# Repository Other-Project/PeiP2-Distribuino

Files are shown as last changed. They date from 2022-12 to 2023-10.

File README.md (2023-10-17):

# Distribuino

<p align=center>
  Resultat final<br />
  <span>Projet réalisé par <a href="https://github.com/06Games">Evan Galli</a> et <a href="https://github.com/TeoBaillot">Téo Baillot d'Estivaux</a> dans le cadre du cours d'<b>Électronique avec Arduino</b></span>
</p>

## Documentation

* [Cahier des charges](docs/cahier_des_charges.md)
* [Répartition du travail](docs/repartition_du_travail.md)
* [Rapports de séance et de projet](docs/rapports_de_seance/README.md)

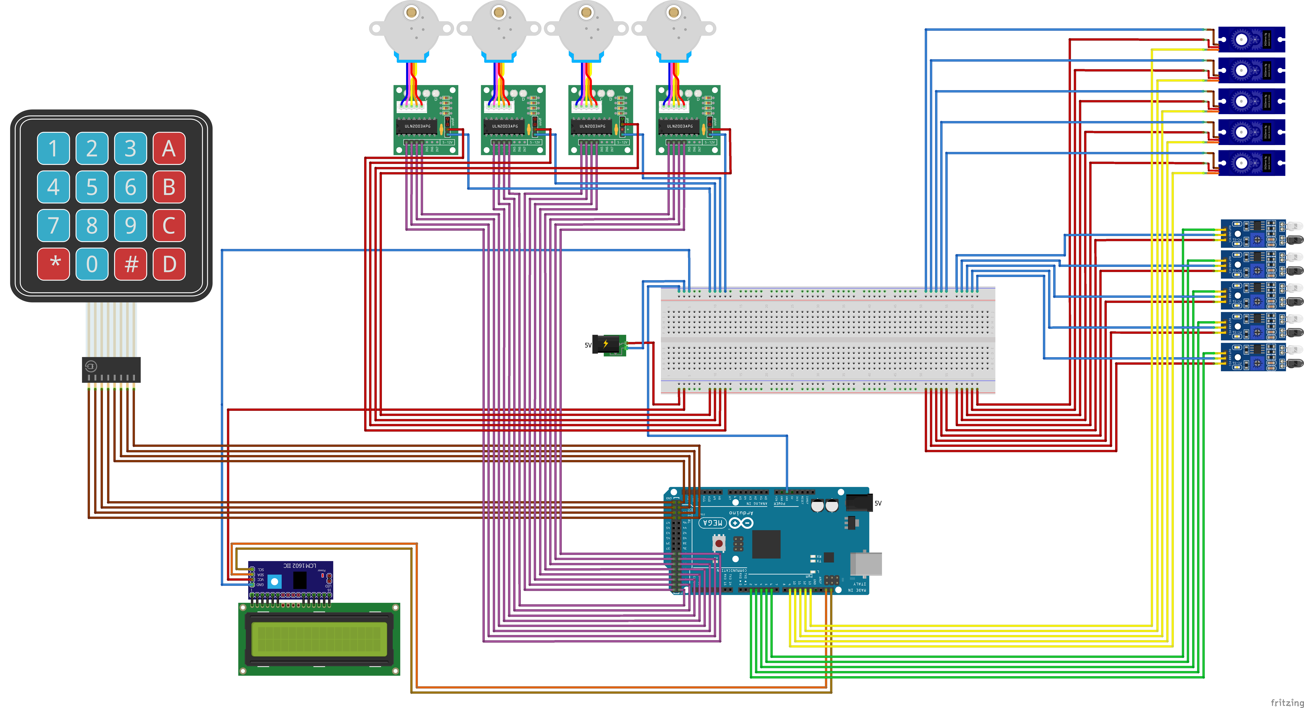
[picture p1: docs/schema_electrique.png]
Schéma électrique


https://github.com/Other-Project/PeiP2-Distribuino/assets/24252743/2bbb648d-e8ed-43b3-9f1b-ac43f1fa2102

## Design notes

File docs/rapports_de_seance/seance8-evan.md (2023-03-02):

# Evan

## Séance 8 : 1 mars 2023

### Fin de la construction des cases

J'ai ajouté le fond sur lequel j'ai fait découper des trous pour les moteurs pas à pas.  
Comme j'avais oublié de faire une encoche pour passer les câbles, j'ai découpé de petites encoches en bas de chaque trous.  
Puis j'ai visser avec des boulons les moteurs pas à pas. 
Malheureusement, il n'y avait pas assez de boulons, je vais devoir en acheter pour visser les moteurs restants.

### Calibrage des capteurs infra-rouge

J'ai essayer de faire fonctionner les capteurs infra-rouge devant capter le passage d'une pièce dans le tube.
Outre certains capteurs defectueux, j'ai remarqué que les capteurs étaient trop éloigné du tube et produisaient beaucoup de faux-positifs.
Téo a donc réduit l'écartement des capteurs à la dremel, ce qui a permi une nette amélioration de la detection.
En revanche, le calibrage n'est toujours pas parfait et la detection ne se fait pas toujours correctement.
Les potentiomètres sont pas assez precis pour un calibrage efficace, comme les capteurs disposent d'une sortie analogique en plus d'une sortie digitale, j'ai la possibilité si necessaire de faire le calibrage dans le code.

https://user-images.githubusercontent.com/24252743/222414979-ab9823aa-37fc-4148-a2f4-29b1150eda77.mp4

### Tests des servo-moteurs servant au rendu des pièces

J'ai fait plusieurs tests pour trouver l'angle nessessaire pour pousser la pièce en dehors du stockage.
En suite, j'ai monté la planche soutenant les pièces sur le reste du distributeur.
Se faisait, j'ai remarqué que la hauteur de certains supports n'etait pas suffisante pour bloquer les pièces supperieure du tube.
Téo a donc fait réimprimer les quelques pièces à changer.

https://user-images.githubusercontent.com/24252743/222415055-9025bd55-9fcc-45de-89fa-96ab0aa629d1.mp4

https://user-images.githubusercontent.com/24252743/222396370-0d3673e9-cfa8-4cbd-a336-67f6afa55b99.mp4

### Réduction du nombre de cables à brancher sur la carte Arduino

Nous avions trop de cables à brancher sur l'arduino mega, j'ai donc du réduire leur nombre.
Pour celà, j'ai utilisé un module HW-061 pour brancher l'écran, ce qui m'as permis de gagner 6 pins sur la carte, ce qui est suffisant ppour tout brancher.

### Correction des problèmes d'alimentation

Au fur et à mesure que je branchait des composants, l'ampérage nessessaire au fonctionnement des éléments était supérieur aux 500mA que peut délivrer la carte Arduino.
Xavier m'as donc dit qu'il fallait procurer 2 alimentations au système, une pour l'arduino (l'inteligence), une pour les composants (la force).

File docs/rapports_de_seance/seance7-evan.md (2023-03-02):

# Evan

## Séance 7 : 15 février 2023

### Construction de la "carcasse"

La dernière fois, nous avions fait découper les planches necessaires à la construction de la boîte.
Lors de la séance, j'ai effectué les forrages obliques afin de pouvoir les visser entre-elles sans que le bois n'éclate et sans que les fixations soit visible de l'exterieur.
En suite, Téo m'a aider à tenir les planches pendant que je les vissais.



### Construction des cases hébergeant les objets

J'ai proposé à Téo de créer des encoches dans les planches constituant les cases afin de pouvoir construire les cases d'un seul tenant, sans nessessité d'ajouter des équaires pour chaque planche.  
Téo a réalisé le dessin vectoriel necessaire et j'ai lancé la découpe sur du bois de 5mm d'épaisseur.  
J'ai en suite pu les assembler. L'assemblage s'est déroulé comme prévu et en très peu de temps (temps, qui est précieux en cette fin de projet), les planches sont bien fixées entre-elles et ne bougent pas.  


### Collage de la glissière du monnaiyeur

J'ai collé la glissière au dessus de la rampe. Celle-ci évite que la pièce ne puisse sortir du rail ainsi que d'éviter qu'elle ne se mette à rouler ce qui empecherait le tri.



### Découpage de la planche de séparation entre les cases et le monnaiyeur

J'ai tracé les traits de découpe sur une planche de 10mm d'épaisseur, puis j'ai demandé à la faire découper.  
Cette planche de 45 cm (L) x 40 cm (H) soutiendra le monnaiyeur puisque les divers élements de celui-ci seront fixés dessus.

### Collage des éléments du monnaiyeur à la planche de séparation

J'ai déterminé les inclinaisons necessaires à ce que les pièces glissent bien (et soient bien triées) tout en minimisant la hauteur occupée.  
J'ai alors déterminé que l'angle du rail devrait etre de 17° et celui de la rampe de rendu de 11°.
Nous avons en suite procédé à leur collage sur la planche de séparation précédamment découpée.


### Détermination de la position des servo-moteurs sur la planche de stockage des pièces

Nous avons (à la louche) déterminé la position des servo-moteurs sur la planche de stockage.
En suite, Téo a fait découper au laser la planche de soutient des pièces et a vissé les servo-moteurs.

https://user-images.githubusercontent.com/24252743/219320475-cbd0ec37-855c-4c8b-9518-73eb0a488ce1.mp4

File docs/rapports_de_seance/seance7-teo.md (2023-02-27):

# Séance 7 Téo Baillot d'Estivaux:  

Depuis la dernière séance on a surtout travaillé à l'assemblage de notre distributeur automatique. J'ai donc fait quelques découpes laser et quelques modélisations 3d dont on avait besoin.  

## Les découpes laser : 

J'ai fait une première découpe laser pour faire une planche qu'on a mis en dessous des tubes afin de soutenir les pièces, la planche comporte des trous qui permettent de fixer les servo-moteurs qui feront tomber les pièces pour rendre la monnaie et d'autres trous qui laisseront simplement passer les pièces de 1, 2, et 5 centimes que nous n'accepteront pas car elles seraient trop compliquées à gérer dans le rendu de la monnaie à cause de leur épaisseur trop faible. Les mesures des endroits qui devaient accueillir les servo-moteurs étaient assez compliquées à faire mais nécessitaient une grande précision donc j'ai dû refaire la planche une seconde fois après un premier essai qui n'avait pas marché. 

  

J'ai également fait les découpes laser des cases qui accueilleront les produits que l'on fera tomber, Evan a eu l'idée de les faire de telle façon qu'elles s'emboitent ce qui nous permet de les monter très rapidement et d'avoir une fixation assez solide.  

  

  

  

J'ai aussi fait la planche qui viendra derrière les cases pour supporter les moteurs pas à pas qui permettront de faire tomber les objets du distributeur.  

  

  

## Les modélisation 3d :  

J'ai fait des supports que l'on va coller sur la planche qui supporte les servo-moteurs car il doit y avoir un écart très précis entre le bas du tube et là où les pièces seront retenues. Cependant, j'ai oublié de tenir compte de la hauteur qui dépasserait du servo-moteur donc j'ai dû recommencer.
Les supports sont de simple carré avec différentes hauteurs qui nous permettent d'adapter la distance entre le bas d'un tube et là où on retient les pièces.  

  

J'ai aussi modélisé des pièces que l'on fixera sur le haut des servo-moteurs car celles qu'on nous donnait n'étaient pas assez longues et ne correspondaient donc pas à nos besoins. J'ai fait le test en imprimant une de ces pièces et elle fonctionne donc j'ai lancé l'impression des autres.  
J'ai fait 3 versions:  

La version 1 :  

Cette première version est assez simple, mais je lui ai trouvé quelques problèmes comme le manque d'un trou pour visser sur le servo-moteur.  

  

  

La version 2 :  

Cette seconde version est plus travaillée, plus fidèle à ce qu'on nous avait donné, mais après réflexion, elle poserait des problèmes à l'impression 3d par exemple à cause des supports que l'on ne pourrait pas enlever à cause de la très faible épaisseur (1.8mm) du bâton qui sort du cylindre.  

  

  

La version 3 :  

J'ai finalement choisi de garder cette version car je me suis dit que c'est celle qui poserait le moins de problème lors de l'impression 3d, je l'ai donc faite avec différentes hauteurs pour que ça s'adapte aux différents supports qui soutiendront les pièces.



  

  

## La partie construction :  

On a assemblé tous les côtés de la boîte à deux car les planches étaient assez lourdes et qu'on voulait être sûr de les mettre correctement, on a décidé de ne pas fixer la partie haute pour le moment ce qui nous permet de manipuler tout ce qu'on met à l'intérieur de la boîte plus facilement et de garder la face avant pour plus tard car on ne connaît pas encore la postion exacte de l'encoche qu'on devra faire pour insérer les pièces. On a fait les découpes et mesures des planches ensemble mais c'est evan qui a fait les trous qui permettront de visser les planches.

  

  

J'ai vissé les capteurs infrarouges dans du bois que j'ai ensuite collé sur les tubes à l'endroit prévu. On a décidé de d'abord visser les capteurs dans du bois pour éviter de visser dans le plastique de peur que ça casse.  

  

J'ai ensuite vissé tous les servo-moteurs sur la planche qui leur était destinée (une première fois à l'envers donc j'ai du tout démonté pour tout refaire car je n'avais pas fait attention).  

  

On a collé les différentes parties du rail qui trie les pièces ensemble :  

  

  

On a ensuite décidé de commencer à construire la partie trieur de pièces, on a donc collé la rampe qui trie les pièces en fonction de leur taille ainsi que toute la partie avec les tubes ( on a préféré le faire à deux car il fallait être assez précis).  

    

  

  

  

## Le test:  

On a testé le fonctionnement des servo-moteurs qui permettront de rendre la monnaie :  

https://user-images.githubusercontent.com/79744829/219315831-a52dc6ba-7ef4-4b65-8d2b-ec19ad241fc2.mp4  

## Conclusion :  

On rattrape petit à petit le retard que l'on a pris à cause du trieur de pièce et le projet commence à prendre forme, on va continuer de travailler en dehors des cours sur le projet sinon on ne pourra pas le finir mais si le rendu de la monnaie fonctionne correctement ( c'est ce qui nous fait le plus peur) on devrait pouvoir rendre notre projet fonctionnel dans les temps.

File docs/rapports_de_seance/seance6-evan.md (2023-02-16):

# Evan

## Séance 6 : 8 février 2023

### Retrait des supports des tubes qui contiendront les pièces

Téo avait fait imprimer les tubes qui contiendront les pièces, ces tubes avaient des supports un peu partout, 
je l'ai donc aidé à enlever les supports d'une partie des tubes pendant qu'il s'occupait des autres

### Collage des divers éléments du monnayeur

#### Trieur

Nous avons collé une petite planche le long de la planche de tri, cette planche soutiendra les pièces lors de leur descente le long du rail de tri.  
Cette planche permet de soutenir les pièces lors de leur descente.  
À la prochaine séance, nous ajouterons une planche de guidage par-dessus pour nous assurer que la pièce reste bien à plat et ne se mette pas à rouler.  
Cela nous permet aussi de nous assurer que la pièce ne sortira pas du rail si l'utilisateur la lance avec une impulsion vers le haut.  
Nous avons déterminé que nous devions pencher le rail de 40° afin que le tri se fasse bien et que nous devions appliquer une pente de 20° afin que la pièce glisse bien.  
Ainsi, afin de pouvoir ultérieurement fixer le rail à une surface verticale, nous avons fait découper de petits tasseaux.






#### Réception

Avec Téo, nous avons collé les différents tubes et glissières sur la planche de réception en bois qu'il avait fait découper au laser.  
Malheureusement, lors du collage, nous n'avons pas réussi à bien positionner les glissières, ce qui cause un décalage au fur et à mesure.  
Nous espérons que cela ne causera pas trop de problèmes.  
La planche de réception étant inclinée de 20° (afin que les pièces glissent bien), nous avons dû faire découper des tasseaux afin de pouvoir la fixer à une surface verticale.







https://user-images.githubusercontent.com/24252743/217789593-29e0c0b9-aa57-4225-9f6d-d5b33a9a447c.mp4

### Détermination des dimensions de notre distributeur

Grâce aux différentes inclinaisons obtenues lors de nos tests, nous avons pu déterminer les dimensions totales du distributeur.  
Notre distributeur mesurera donc 50 cm (l) x 50 cm (L) x 44 cm (H)  
Nous avons ensuite fait découper les différentes faces.

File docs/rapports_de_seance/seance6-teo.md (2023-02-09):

# Séance 6 Téo Baillot d'Estivaux:  

Aujourd'hui on a commencé l'assemblage de notre distributeur car j'ai fait chez moi les modélisations et découpes laser nécessaires à l'assemblage du trieur de pièce et on a fait des tests sur le trieur de pièces.  

## Les modélisations :  

J'ai refait la modélisation des tubes et des rampes qui étaient trop compliquées à faire en bois.  

  

  

## Les découpes laser :  

J'ai fait les découpes laser du guide qui sera juste au-dessus de celle qui trie les pièces en fonction de leur taille afin d'éviter que la pièce saute et être sûr que le tri se fait correctement.  

  

La rampe qui va guider les pièces vers le tube :  

  

La rampe qui ramènera la monnaie rendu à l'utilisateur :  

  

## Le début de l'assemblage :  

On a découpé les planches pour faire l'extérieur de la boite et une planche qui viendra à l'intérieur de la boîte sur laquelle on va fixer le système de trie des pièces, on a enlevé tous les supports des modélisations 3d, on a collé tous les tubes et tous les guides sur la rampe qui accompagne les pièces aux tubes, et on a fait des tasseaux pour soutenir la rail qui triera les pièces en fonction de leur taille et le rail qui guide les pièces vers les tubes.  

  

  

  

  

  

  

  

## Les tests :  

On a testé les différentes positions d'angles dans laquelle on pourrait mettre la rampe qui trie les pièces en fonction de leur taille ce qui nous a permis de déterminer la taille que prendra le système de trie et dimensionner la boîte.  

On a aussi testé que les pièces étaient bien guidées dans la rampe qui va vers les tubes et qu'elles rentraient correctement dans les tubes :  

https://user-images.githubusercontent.com/79744829/217796409-5acfa904-5b46-4af0-a7f6-d8ce901cf2a7.mp4  

## Conclusion :  

Notre projet commence à prendre forme et on s'est rendu compte que la construction va nous prendre beaucoup plus de temps que prévu. Il y a beaucoup de choses dans le compte-rendu car j'ai travaillé entre les séances.

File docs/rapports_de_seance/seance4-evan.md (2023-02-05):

# Evan

## Séance 4 : 18 janvier 2023

### Présentation orale du projet

Avec Téo, nous avons présenté notre projet durant 5 minutes à un jury composé de M. Charlon et de M. Peter puis, tous deux nous on posé quelques questions et on émit des recommandations pour la suite du projet.

### Gestion des articles

J'ai implémenté un système de gestion des articles capable de connaitre le prix des articles ainsi que de vérifier la validé du code entré

Dans un premier temps, j'ai utilisé la librairie [Dictionary](https://www.arduino.cc/reference/en/libraries/dictionary/) qui m'a permis d'associer un prix à un code article

```cpp
#include <Keypad.h>
#include <LiquidCrystal.h>
#include <Stepper.h>

const int ROW_NUM = 4; //four rows
const int COLUMN_NUM = 4; //four columns
char keys[ROW_NUM][COLUMN_NUM] = {
  {'1','2','3', 'A'},
  {'4','5','6', 'B'},
  {'7','8','9', 'C'},
  {'*','0','#', 'D'}
};
byte pin_rows[ROW_NUM] = {47, 49, 51, 53}; //connect to the row pinouts of the keypad
byte pin_column[COLUMN_NUM] = {46, 48, 50, 52}; //connect to the column pinouts of the keypad
Keypad keypad = Keypad(makeKeymap(keys), pin_rows, pin_column, ROW_NUM, COLUMN_NUM);

LiquidCrystal lcd(31, 33, 35, 30, 32, 34);

const int stepsPerRevolution = 2048;
const int rpm = 16;
Stepper stepper1 = Stepper(stepsPerRevolution, 8, 10, 9, 11);

Dictionary &d = *(new Dictionary(4));

const int codeLength = 4;
String productCode = "";

void setup(){
  Serial.begin(9600);
  lcd.begin(16, 2);
  stepper1.setSpeed(rpm);
  d("123A", 2.5);
  d("456B", 2.0);
}

void loop(){
  char key = keypad.getKey();

  if (key) {
    if(key == '*' | key == '#') productCode = ""; // Cancel
    else if(productCode.length() < codeLength) productCode += key;
  }
  
  writeToScreen(0, "Distribuino v0.3");
  if(productCode == "") writeToScreen(1, "Code produit ?");
  else if(productCode.length() == codeLength) 
  {
    if(d(productCode)) {
        writeToScreen(1, "Inserer " + String(d[productCode]) + "e");
        delay(5000);
        writeToScreen(1, "Distribution...");
        stepper1.step(-stepsPerRevolution);
        productCode = "";
    }
  }
  else writeToScreen(1, productCode);
}

void writeToScreen(int line, String text) {
  // Clears the screen line
  for(int i = 0; i < 16; i++){
    lcd.setCursor(i, line);
    lcd.write(" ");
  }

  // Writes the text
  lcd.setCursor(0, line);
  lcd.print(text);
}
```

https://user-images.githubusercontent.com/24252743/213459873-f7ff2302-5194-409e-a2dc-9b17383bf209.mp4

En suite, j'ai souhaité pouvoir afficher le nom de l'article sélectionné, j'ai donc créé une structure afin de faciliter l'accès aux données
```cpp
struct Item {
  String itemCode;
  String itemName;
  float itemPrice;
};
```

Mais je me suis rendu compte que la librairie que j'utilisais pour le dictionnaire ne les supportait pas.  
J'ai donc opté pour utiliser une simple liste dans laquelle le programme va itérer à la recherche de l'article

```cpp
#include <Keypad.h>
#include <LiquidCrystal.h>
#include <Stepper.h>
#include <Dictionary.h>

struct Item {
  String itemCode;
  String itemName;
  float itemPrice;
};

const int ROW_NUM = 4; //four rows
const int COLUMN_NUM = 4; //four columns
char keys[ROW_NUM][COLUMN_NUM] = {
  {'1','2','3', 'A'},
  {'4','5','6', 'B'},
  {'7','8','9', 'C'},
  {'*','0','#', 'D'}
};
byte pin_rows[ROW_NUM] = {47, 49, 51, 53}; //connect to the row pinouts of the keypad
byte pin_column[COLUMN_NUM] = {46, 48, 50, 52}; //connect to the column pinouts of the keypad
Keypad keypad = Keypad(makeKeymap(keys), pin_rows, pin_column, ROW_NUM, COLUMN_NUM);

LiquidCrystal lcd(31, 33, 35, 30, 32, 34);

const int stepsPerRevolution = 2048;
const int rpm = 16;
Stepper stepper1 = Stepper(stepsPerRevolution, 8, 10, 9, 11);

Item items[] = {
  {"123A", "Bonbons", 2.5},
  {"456B", "Kitkat", 2.0},
  {"789C", "", 2.1},
  {"0000", "C'est un code pin", 3.0}
};

const int codeLength = 4;
String productCode = "";

void setup(){
  Serial.begin(9600);
  lcd.begin(16, 2);
  stepper1.setSpeed(rpm);
}

void loop(){
  char key = keypad.getKey();

  if (key) {
    if(key == '*' | key == '#') productCode = ""; // Cancel
    else if(productCode.length() < codeLength) productCode += key;
  }
  
  writeToScreen(0, "Distribuino v0.3");
  if(productCode == "") writeToScreen(1, "Code produit ?");
  else if(productCode.length() == codeLength) 
  {
    for(int i = 0; i <= 4; i++){
      if(i == 4)
      {
        writeToScreen(1, "Code invalide");
        delay(5000);
        productCode = "";
      }
      else if(items[i].itemCode == productCode) {
        writeToScreen(0, items[i].itemName);
        writeToScreen(1, "Inserer " + String(items[i].itemPrice) + "e");
        delay(5000);
        writeToScreen(1, "Distribution...");
        stepper1.step(-stepsPerRevolution);
        productCode = "";
        break;
      } 
    }
  }
  else writeToScreen(1, productCode);
}

void writeToScreen(int line, String text) {
  // Clears the screen line
  for(int i = 0; i < 16; i++){
    lcd.setCursor(i, line);
    lcd.write(" ");
  }

  // Writes the text
  lcd.setCursor(0, line);
  lcd.print(text);
}
```

https://user-images.githubusercontent.com/24252743/213457605-0a6aa33a-0515-48f7-81d4-5080b71538fd.mp4

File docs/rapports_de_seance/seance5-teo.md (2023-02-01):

# Séance 5 Téo Baillot d'Estivaux:  
Aujourd'hui on a récupéré la modélisation 3d du trieur de pièce qui a été imprimé mais on a fait face à de nombreux problèmes. La pièce avait été découpée en deux morceaux et ni l'un ni l'autre n'a été utilisable. Je me suis donc résolu à refaire le système de tri depuis le début en grande partie en bois plutôt que de le réimprimer.  

## Les problèmes de la partie haute de la modélisation:  

Je me suis rendu compte que j'avais fait une erreur de cotation lors de la modélisation, les dimensions de la fente pour insérer les pièces étaient trop petites et l'écart entre le rail pour trier les pièces et le rail d'au-dessus qui devait permettre de guider les pièces qui avaient le même espacement que la fente était donc trop petite aussi. On a donc voulu limer la fente pour l'agrandir et retirer le rail qu'il y avait au-dessus du rail pour retenir les pièces avec une dremel mais cela a fait fondre le plastique et nous a donc rajouté un problème. On a donc ensuite essayé de poncer le plastique pour le remettre à la hauteur voulue mais c'était très imprécis et a changé l'écart entre l'endroit où devait rouler la pièce et le haut de chaque trou du rail pour trier les pièces.
On a donc réussi à faire en sorte que les pièces soient triées mais elles ne se triaient pas comme on le voulait et comme ce n'était parfaitement lisse parfois les pièces sautaient.  

De plus, on avait récupéré la partie haute avec quelques endroits du bas cassés au niveau du guide vers le tri de stockage.  

  

  

https://user-images.githubusercontent.com/79744829/216055010-b539d415-488c-426f-9a1e-61f5f9b7d00a.mp4  

Face à tous ses problèmes et malgré plus d'une heure de tentatives pour régler le problème on a décidé d'abandonner la partie haute du système de tri à notre plus grand regret.

## Les problèmes de la partie basse de la modélisation:  

La partie basse a eu beaucoup de problèmes mais qui cette fois-ci n'étaient pas liés à moi mais à des problèmes de modélisation.

Tout d'abord, il y a eu énormément des supports qui ont surement fondu lors de l'impression et qui sont devenu aussi solides que la partie que l'on voulait garder donc c'était très difficile de les enlever.

De plus, la modélisation a été imprimée à plat alors que notre pièce avait un angle donc il y a eu une grosse couche imprimée dont on ne voulait pas:  

  

  

  

Il y avait aussi des supports impossibles à enlever qui bouchaient les tubes de stockage des pièces et des supports qui étaient aussi très difficiles à enlever au-dessus et en dessous des plateformes qui devaient accueillir les servo-moteurs et retenir les pièces ne faisant qu'un bloc de plastique donc impossible d'enlever de façon suffisamment précise pour que la plateforme reste à 1.5 fois l'épaisseur d'une pièce en dessous du tube:  

  

On a tout de même essayé d'enlever les supports mais au bout d'une heure on a bien vu qu'on n'arriverait pas à tout enlever comme on voulait donc on a aussi, a notre plus grand regret, abandonné la partie basse de la modélisation.

## La solution:  

J'ai passé énormément de temps à faire la modélisation et on a passé beaucoup de temps à essayer de résoudre les problèmes une fois qu'elle avait été imprimée donc on a perdu énormément de temps pour faire le trieur en modélisation 3d sans succès.  

Je tiens quand même à ce qu'on ait un trieur de pièce donc je ne vais pas abandonner et je vais en refaire un mais cette fois il sera principalement en bois. 

## Le début du nouveau trieur:  

J'ai découvert le site Inkscape pour faire des découpes laser que j'ai donc dû prendre en main et j'ai fait la rampe de trie des pièces qui cette fois marche. 



https://user-images.githubusercontent.com/79744829/216062290-51b9a979-9d02-46e9-9bfa-1d73d8cbd94c.mp4  

J'ai aussi refait des modélisations de tubes qui ressemblent au premier en modélisation 3d car j'ai pensé que pour les tubes la modélisation 3d restait le plus simple. J'en ai fait un et l'ai fait imprimer pour voir si ça marchait avant de faire et d'imprimer les autres sauf qu'il y a encore eu un problème à l'impression car les supports qui ont été mis était aussi durs que la modélisation donc ne pouvait pas être enlevés et remplissaient l'intérieur de tube empêchant les pièces de passer. On a donc relancer une nouvelle fois l'impression.  

  

## Conclusion:  

Dans ce compte rendu je raconte beaucoup de choses car j'ai passé beaucoup de temps à travailler le projet en dehors des cours pour rattraper le retard accumulé.  

Je repars donc de 0 pour faire le système de tri des pièces mais reste très motivé.

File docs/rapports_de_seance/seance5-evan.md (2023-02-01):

# Evan

## Séance 5 : 1 février 2023

### Travail au FabLab

> Voir le [compte rendu de Téo](seance5-teo.md) pour plus de détails sur les problèmes rencontrés

J'ai aidé Téo à enlever les supports de la partie basse de notre système de tri qui a été imprimé durant la semaine de ski.  
Malgrès tout nos efforts, la pièce reste innutilisable, les supports étant plus dure que la pièce elle-même.

En suite, nous avons essayé de corriger une erreure de cotation sur la rampe de tri, nous avons retiré la partie suppérieure de la rampe à la Dremel car celle-ci était trop proche de la rampe en elle-même. En retirant la partie suppérieure, le soutient des pièces avait en partie fondu, ce qui couplé avec une marge de seulement 1mm en bas des trous, ne permettait plus le passage des pièces. Nous avons alors poncé le support, mais en poncant, nous avons retirer plus de matière que necessaire et les pièces ne tombait plus dans les bons compartiments.

Nous nous somme résolus à refaire entièrement le système de tri, mais en limitant cette fois l'impression 3D au strict minimum, le reste sera fait en bois.

### Amélioration de la lisibilité du code

J'ai divisé le code en plusieurs fonctions afin d'en améliorer la lisibilité ainsi que pour en faciliter la modification dans le futur.
Afin de passer l'article séléctionné d'une fonction à une autre, j'ai utilisé un pointeur ce qui à l'avantage de pouvoir renvoyer une valeur `null` contrairement à un passage d'instance classique et qui permet un accès direct à l'article contrairement à l'index.

```cpp
#include <Keypad.h>
#include <LiquidCrystal.h>
#include <Stepper.h>

struct Item {
  String itemCode;
  String itemName;
  float itemPrice;
};

const int ROW_NUM = 4; //four rows
const int COLUMN_NUM = 4; //four columns
char keys[ROW_NUM][COLUMN_NUM] = {
  {'1','2','3', 'A'},
  {'4','5','6', 'B'},
  {'7','8','9', 'C'},
  {'*','0','#', 'D'}
};
byte pin_rows[ROW_NUM] = {47, 49, 51, 53}; //connect to the row pinouts of the keypad
byte pin_column[COLUMN_NUM] = {46, 48, 50, 52}; //connect to the column pinouts of the keypad
Keypad keypad = Keypad(makeKeymap(keys), pin_rows, pin_column, ROW_NUM, COLUMN_NUM);

LiquidCrystal lcd(31, 33, 35, 30, 32, 34);

const int stepsPerRevolution = 2048;
const int rpm = 16;
Stepper stepper1 = Stepper(stepsPerRevolution, 8, 10, 9, 11);

Item items[] = {
  {"123A", "Bonbons", 2.5},
  {"456B", "Kitkat", 2.0},
  {"789C", "", 2.1},
  {"0000", "C'est un code pin", 3.0}
};

const int codeLength = 4;

void setup() {
  Serial.begin(9600);
  lcd.begin(16, 2);
  stepper1.setSpeed(rpm);

  for(int i = 0; i < captors; i++) pinMode(coinCaptors[i].pin, INPUT);
}

void writeToScreen(int line, String text) {
  // Clears the screen line
  for(int i = 0; i < 16; i++){
    lcd.setCursor(i, line);
    lcd.write(" ");
  }

  // Writes the text
  lcd.setCursor(0, line);
  lcd.print(text);
}

String waitForCode(){
  writeToScreen(0, "Distribuino v0.3");
  writeToScreen(1, "Code produit ?");

  String productCode = "";
  while(productCode.length() < codeLength) {
    char key = keypad.getKey();
    if (key) {
      if(key == '*' | key == '#') return waitForCode(); // Cancel
      else productCode += key;
      
      writeToScreen(1, productCode);
    }
  }
  return productCode;
}

Item* checkCode(String productCode) {
  for(int i = 0; i <= 4; i++) {
      if(i == 4)
      {
        writeToScreen(1, "Code invalide");
        delay(5000);
        productCode = "";
        return NULL;
      }
      else if(items[i].itemCode == productCode) {
        writeToScreen(0, items[i].itemName);
        writeToScreen(1, "Inserer " + String(items[i].itemPrice) + "e");
        return &items[i];
      }
    }
}

void waitForCoins(Item* item) {
  delay(5000);
}

void loop() {
  String productCode = waitForCode();
  Item* item = checkCode(productCode);
  if (item == NULL) return;

  waitForCoins(item);
  writeToScreen(1, "Distribution...");
  stepper1.step(-stepsPerRevolution);
}
```

### Détection des pièces

Après avoir nétoyé le code, je me suis attelé à la détection des pièces.
Il y aura un capteur pour chaque pièces (la valeur ayant été trié grace à une rampe qui fait tomber les pièces en fonction de leur taille).
Il me suffit donc de compter le nombre de passage devant chaque capteur pour déterminer la valeur des pièces incérées.
La fonction `waitForCoins` que j'ai prévu à cet effet, retourne un `float` qui contient la valeur à rendre à la fin de la transaction (dans le cas, où l'utilisateur a mis plus que nécessaire).

```cpp
#include <Keypad.h>
#include <LiquidCrystal.h>
#include <Stepper.h>

struct Item {
  String itemCode;
  String itemName;
  float itemPrice;
};

struct Coin {
  int pin;
  float coinValue;
};

const int ROW_NUM = 4; //four rows
const int COLUMN_NUM = 4; //four columns
char keys[ROW_NUM][COLUMN_NUM] = {
  {'1','2','3', 'A'},
  {'4','5','6', 'B'},
  {'7','8','9', 'C'},
  {'*','0','#', 'D'}
};
byte pin_rows[ROW_NUM] = {47, 49, 51, 53}; //connect to the row pinouts of the keypad
byte pin_column[COLUMN_NUM] = {46, 48, 50, 52}; //connect to the column pinouts of the keypad
Keypad keypad = Keypad(makeKeymap(keys), pin_rows, pin_column, ROW_NUM, COLUMN_NUM);

LiquidCrystal lcd(31, 33, 35, 30, 32, 34);

const int stepsPerRevolution = 2048;
const int rpm = 16;
Stepper stepper1 = Stepper(stepsPerRevolution, 8, 10, 9, 11);

const int captors = 1;//5;
const Coin coinCaptors[] = {
  {41, 0.5},
  /*{42, 0.2},
  {43, 0.5},
  {44, 1.0},
  {45, 2.0}*/
};

Item items[] = {
  {"123A", "Bonbons", 2.5},
  {"456B", "Kitkat", 2.0},
  {"789C", "", 2.1},
  {"0000", "C'est un code pin", 3.0}
};

const int codeLength = 4;

void setup() {
  Serial.begin(9600);
  lcd.begin(16, 2);
  stepper1.setSpeed(rpm);

  for(int i = 0; i < captors; i++) pinMode(coinCaptors[i].pin, INPUT);
}

void writeToScreen(int line, String text) {
  // Clears the screen line
  for(int i = 0; i < 16; i++){
    lcd.setCursor(i, line);
    lcd.write(" ");
  }

  // Writes the text
  lcd.setCursor(0, line);
  lcd.print(text);
}

String waitForCode(){
  writeToScreen(0, "Distribuino v0.3");
  writeToScreen(1, "Code produit ?");

  String productCode = "";
  while(productCode.length() < codeLength) {
    char key = keypad.getKey();
    if (key) {
      if(key == '*' | key == '#') return waitForCode(); // Cancel
      else productCode += key;
      
      writeToScreen(1, productCode);
    }
  }
  return productCode;
}

Item* checkCode(String productCode) {
  for(int i = 0; i <= 4; i++) {
      if(i == 4)
      {
        writeToScreen(1, "Code invalide");
        delay(5000);
        productCode = "";
        return NULL;
      }
      else if(items[i].itemCode == productCode) {
        writeToScreen(0, items[i].itemName);
        writeToScreen(1, "Inserer " + String(items[i].itemPrice) + "e");
        return &items[i];
      }
    }
}

float waitForCoins(Item* item) {
  unsigned long dernierPassage; // Contiendra le temps écoulé depuis le début du programme
  bool detected[captors];
  float sum = 0;

  while(sum < item->itemPrice) {
    if(millis()-dernierPassage < 250) continue;
    for(int i = 0; i < captors; i++){
      
      // On teste si le capteur infrarouge détecte un passage 
      // On vérifie qu'aucun objet n'ait été détecté moins de 250 millisecondes plus tôt.
      if (digitalRead(coinCaptors[i].pin) == LOW && !detected[i]) {
        detected[i] = true;
        
        Serial.print("pièce de ");
        Serial.print(coinCaptors[i].coinValue);
        Serial.println(" détectée");
        
        sum += coinCaptors[i].coinValue; // On incrémente le nombre de passages détectés par le capteur

        float remaining = item->itemPrice - sum;
        if(remaining > 0) writeToScreen(1, "Inserer " + String(remaining) + "e");
      }
      else detected[i] = false;
    }
    dernierPassage = millis(); // On sauvegarde le temps écoulé entre le lancement du programme et ce passage
  }
  return -sum;
}

void loop() {
  String productCode = waitForCode();
  Item* item = checkCode(productCode);
  if (item == NULL) return;

  waitForCoins(item);
  writeToScreen(1, "Distribution...");
  stepper1.step(-stepsPerRevolution);
}
```

https://user-images.githubusercontent.com/24252743/216056331-b4e8a50e-33cd-4e0c-b6ae-04efc0cd1f4b.mp4



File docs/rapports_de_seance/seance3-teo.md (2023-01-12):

#  Séance 3 Téo Baillot d'Estivaux:  

Aujourd'hui j'ai continué la modélisation du système de tri de pièces. J'ai découvert en ouvrant ma modélisation que certaines esquisses s'étaient décallées et que la modélisation n'était pas dans l'état dans lequel je l'avais laissée peut-être parce que je l'avais mal enregistrée.
J'ai donc perdu pas mal de temps à tout remettre correctement et j'ai ensuite commencé à réfléchir à comment j'allais placer les capteurs sur les tubes. Finalement un capteur infrarouge sera placé en haut de chaque tube de façon à détecter lorsqu'une pièce entre et lorsque le tube est plein.  

Il y avait quand même le risque que l'épaisseur de la pièce soit trop faible et empêche le capteur de la détecter. J'ai donc préféré tester le fonctionnement du capteur afin de m'assurer qu'il détectera bien la pièce lorsqu'elle passera devant avant de faire cette partie de la modélisation.  

Pour finir j'ai commencé la modélisation de la plateforme qui sera en dessous des tubes à 1.5 fois l'épaisseur de la pièce en question de distance et qui accueillera le servo-moteur qui permettra de faire sortir les pièces une par une du tube pour rendre la monnaie.  

J'avais prévu de faire la modélisation du système de tri des pièces en 3 séances, donc je n'ai pas réussi à respecter ce délai, mais j'ai tout de même bien avancé car j'ai déjà fait le fonctionnement des capteurs infrarouges.
A la prochaine séance, il ne restera plus qu'à finir le peu qu'il reste à faire sur les plateformes pour pouvoir y insérer le servo-moteur et à faire la rampe qui accompagnera les pièces à la sortie de la machine.  

L'objectif est donc de lancer l'impression du système de tri de pièce et de coder le rendu de la monnaie grâce aux servo-moteurs lors de la prochaine séance.

## Le fonctionnement du capteur infrarouge:
Le principe de fonctionnement du capteur est le suivant: le capteur est équipé d'un émetteur de lumière infrarouge et d'un récepteur qui détecte l'intensité de la réflexion lumineuse. Ainsi si un obstacle se trouve dans le champ de vision du capteur, la radiation sera réfléchie par l'obstacle et le récepteur la mesurera. Le potentiomètre (carré bleu) nous permet de régler cette distance.  

  

J'ai choisi de prendre un capteur qui se fixera à la verticale au tube et qui ne nécéssite qu'un trou car c'est ce qui est le plus adapté à nos besoins.  

Pour le moment le programme que j'ai fait est assez simple et a juste permis de détecter si une pièce passait devant et de compter le nombre de pièces qui est passé devant.  

```cpp
// Permet de compter le nombre de passages de la pièce devant le capteur infrarouge

const int INFRAROUGE1= 10;
int nombrePieces = 0;
unsigned long dernierPassage = 0;
unsigned long temps = 100; // Contiendra le temps écoulé depuis le début du programme

void setup(){
  pinMode(INFRAROUGE1,INPUT);
  Serial.begin(9600); // vitesse de communication avec l'arduino
}

void loop(){
  // On teste si le capteur infrarouge détecte un passage 
  // On vérifie qu'aucun objet n'ait été détecté moins de 100millisecondes plus tôt.
  if (digitalRead(INFRAROUGE1)==LOW && millis()-dernierPassage>=100){ 
    Serial.println("pièce détectée");
    nombrePieces+=1; // On incrémente le nombre de passages détectés par le capteur
    dernierPassage = millis(); // On sauvegarde le temps écoulé entre le lancement du programme et ce passage
    Serial.print("Nombre de pièces :"); // On affiche le nombre de passages sur le moniteur série
    Serial.println(nombrePieces);
  }
}
``` 

  

https://user-images.githubusercontent.com/24252743/212019928-68504ad0-9cb5-4a2b-b036-74bf6e9d8f75.mp4

https://user-images.githubusercontent.com/24252743/212019966-c19988e2-a1df-4e1a-bad1-67831ce1d69a.mp4

## La partie modélisation:  

J'ai fait un trou sur chaque tube qui acceuillera le capteur, il faudra peut-être faire quelques modification de cotes car il ne faudrait pas que le capteur dépasse à l'intérieur du tube ce qui pourrait géner le passage des pièces.  



J'ai aussi fait simplement ces plateformes, la partie de droite accueillera les pièces et celle de gauche le servo-moteur qui permettra de rendre la monnaie.  




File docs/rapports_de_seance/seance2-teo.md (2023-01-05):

# Séance 2 Téo Baillot d'Estivaux:
Au cours de cette séance j'ai continué la modélisation du trieur de pièce qui sera dans le distributeur et qui permettra de rendre la monnaie. J'ai fait le trou afin de faire rentrer les pièces que j'avais oublié de faire à la première séance et j'ai fait la partie qui permet de stocker les pièces.  

La difficulté de cette séance a été que étant donné que chaque tube qui permettait de stocker les pièces n'avait pas la même dimension que les autres, je n'ai donc pas pu faire une figure et la répéter plusieurs fois donc j'ai fait les figures une par une ce qui m'a pris énormément de temps.  

## Le trou qui permettant d'insérer les pièces:
Le trou a été dimensionné de façon à ce que toutes les pièces puissent rentrer et être guidées correctement dans le rail.  




### La partie qui permet de stocker les pièces:
J'ai plus ou moins fait la même esquisse sur plusieurs plans de façon à pouvoir extruder les tubes de la façon voulu.  

J'ai aussi fait un rail qui permet d'accompagner les pièces vers le trou du tube dans lequel les pièces vont tomber en minimisant au maximum les chances que la pièce se coince avant d'arriver dans le tube ou dans le tube.  

Les tubes ont été dimensionnés de façon à pouvoir acceuillir un minimum de 10 pièces en prenant en compte le fait que des trous seront rajouté sur les tubes afin d'acceuillir les capteurs qui permettront de détecter quand une pièce entre dans la machine ou si un tube est pleins.  

L'espace entre chaque tube permettra aussi d'acceuillir une plateforme qui permettra de fixer des servo-moteurs qui permettront de rendre la monnaie et une sorte de planche qui permettra de retenir les pièces.  








Pour finir j'ai fait pas mal d'esquisse afin d'avoir un rendu plus propre des tubes car certaines parties extrudées depassaient.


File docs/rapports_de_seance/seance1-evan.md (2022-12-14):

# Evan

## Séance 1 : 14 décembre 2022

### Démontage d'un précédent projet de distributeur automatique
J'ai procédé à la récupération des moteurs pas à pas, du système de tri des pièces et des divers autres composants.  
Lors du démontage, j'ai pris soin d'observer les circuits réalisés par le précédent groupe ainsi que les choix qui avaient été effectués.
Cela a aussi été l'occasion de discuter du fonctionnement du tri des pièces, en observant ce qui a pu être réalisé dans ce projet ainsi que dans celui de la tirelire et du distributeur de billets.

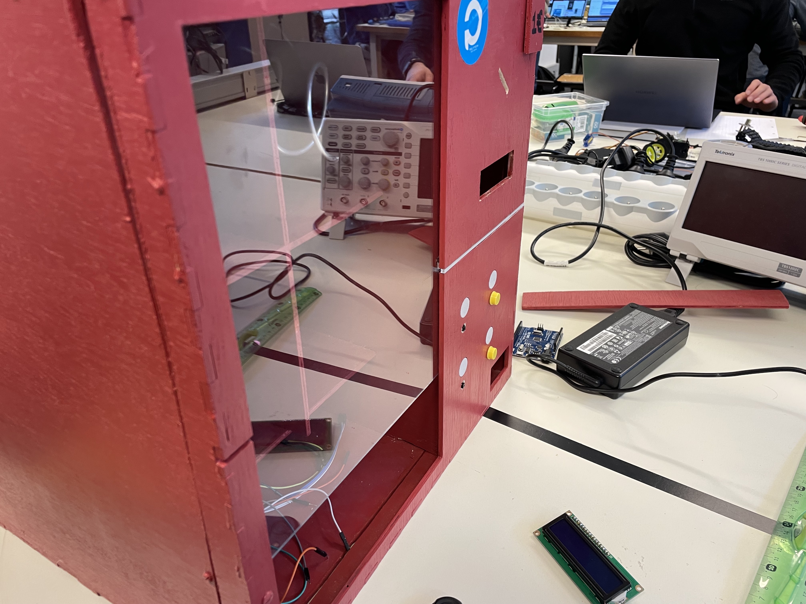
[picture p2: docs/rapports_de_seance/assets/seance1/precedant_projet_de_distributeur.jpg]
Précédent projet de distributeur

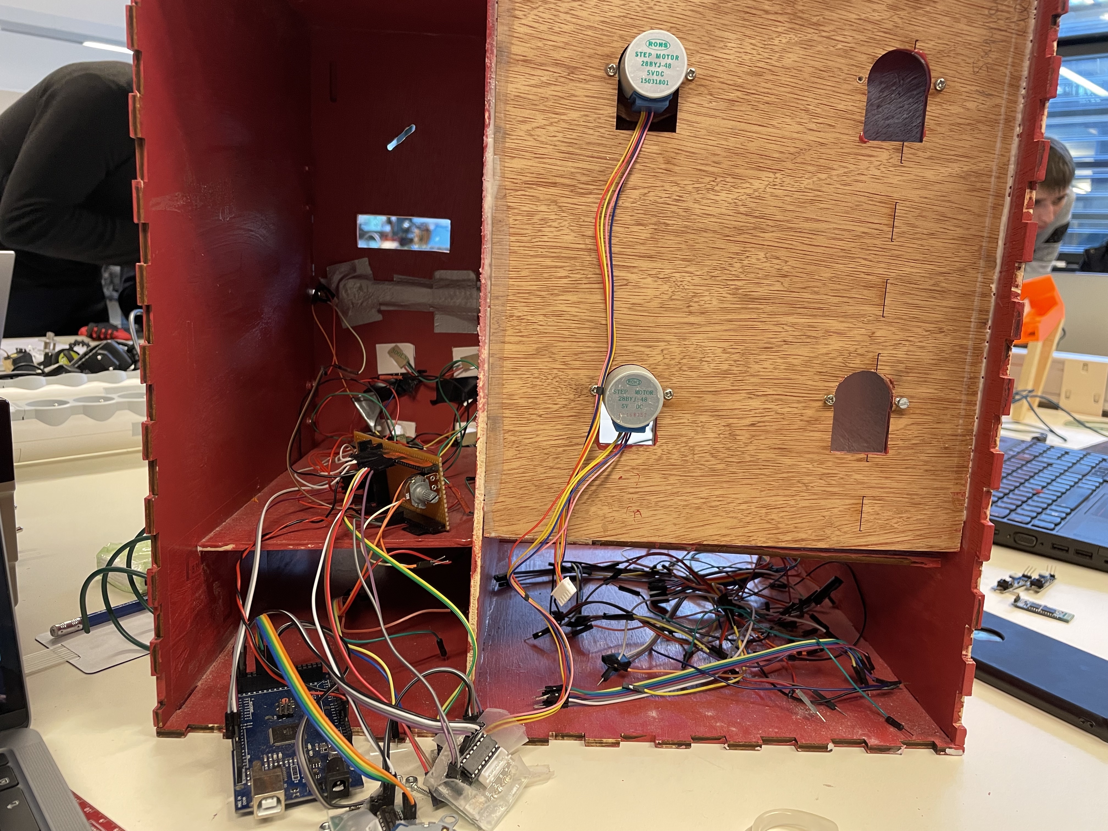
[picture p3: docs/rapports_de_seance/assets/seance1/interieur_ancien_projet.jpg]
Intérieur de l'ancien projet

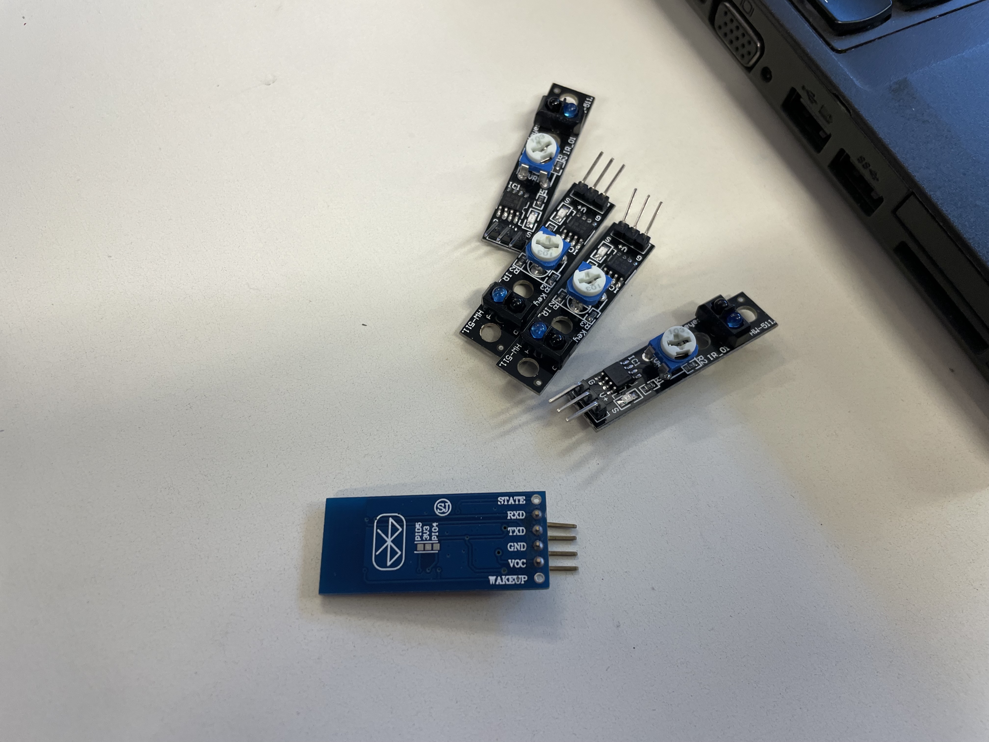
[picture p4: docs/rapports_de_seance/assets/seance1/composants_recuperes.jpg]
Composants récupérés

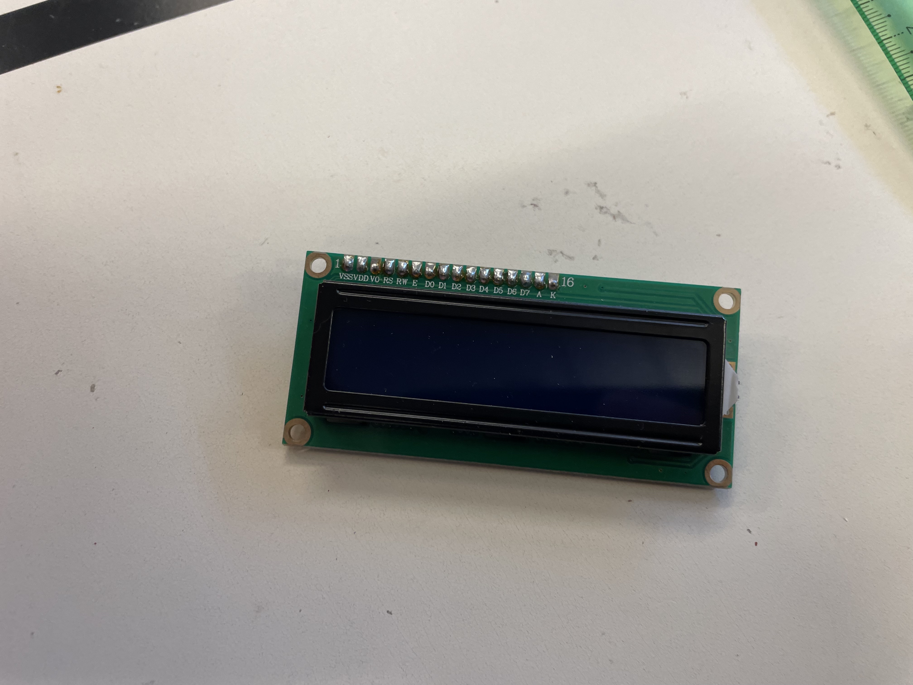
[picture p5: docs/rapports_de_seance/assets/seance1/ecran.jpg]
Écran


### Tests de fonctionnement des moteurs pas-à-pas
À partir des branchements de l'ancien projet, j'ai pu isoler la partie dédiée au fonctionnement des moteurs pas à pas.  
Celle-ci utilise un `ULN2003APG` pour gérer les contrôles.  
J'ai utilisé la librairie [Stepper](https://docs.arduino.cc/learn/electronics/stepper-motors) pour communiquer avec la puce qui contrôle le moteur pas à pas.  

Exemple de code :

```cpp
#include <Stepper.h>
const int stepsPerRevolution = 2048;
const int rpm = 12;
Stepper stepper1 = Stepper(stepsPerRevolution, 8, 10, 9, 11);

void setup() {
  stepper1.setSpeed(rpm);
}

void loop() {
  stepper1.step(-stepsPerRevolution);
}
```

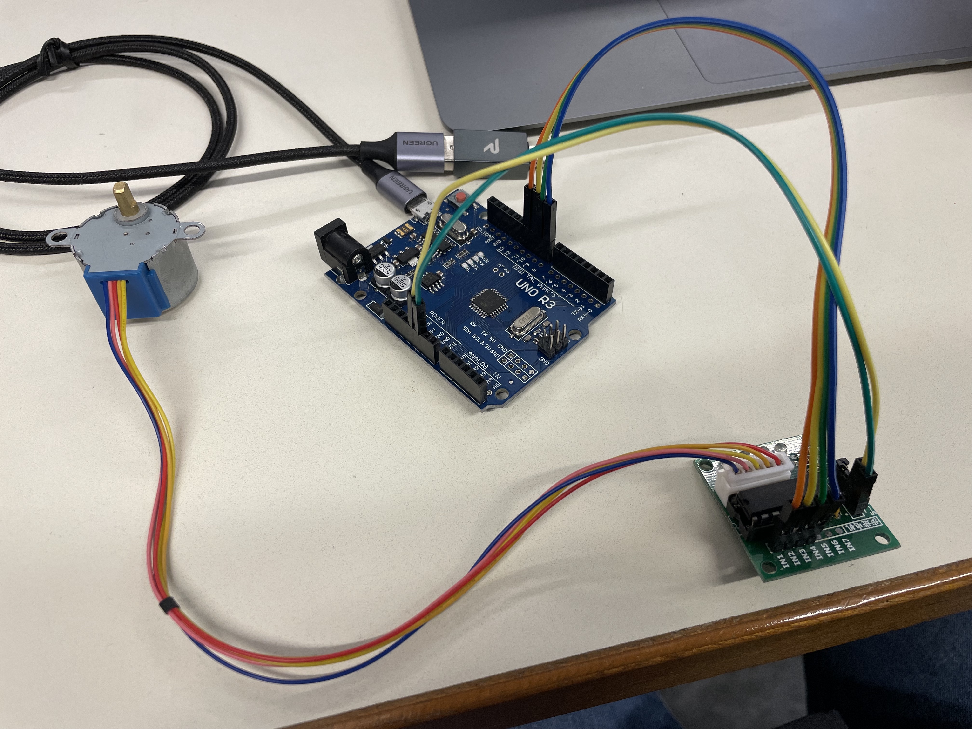
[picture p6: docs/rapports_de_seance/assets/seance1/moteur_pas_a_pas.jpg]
Moteur pas-à-pas

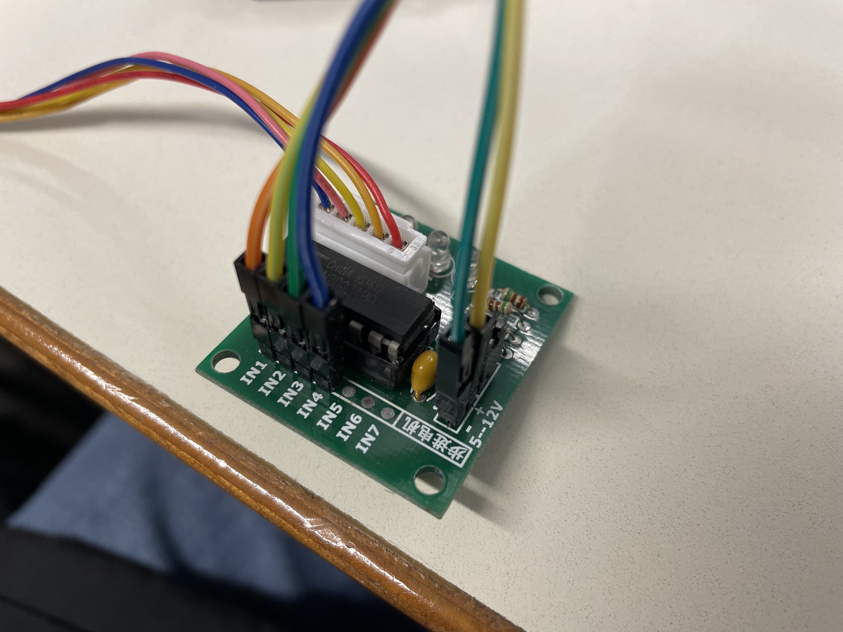
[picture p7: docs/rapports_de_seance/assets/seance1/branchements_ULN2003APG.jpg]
Branchements ULN2003APG


https://user-images.githubusercontent.com/24252743/207671176-315f9538-9d44-416a-b018-0a31de14a4c6.mp4

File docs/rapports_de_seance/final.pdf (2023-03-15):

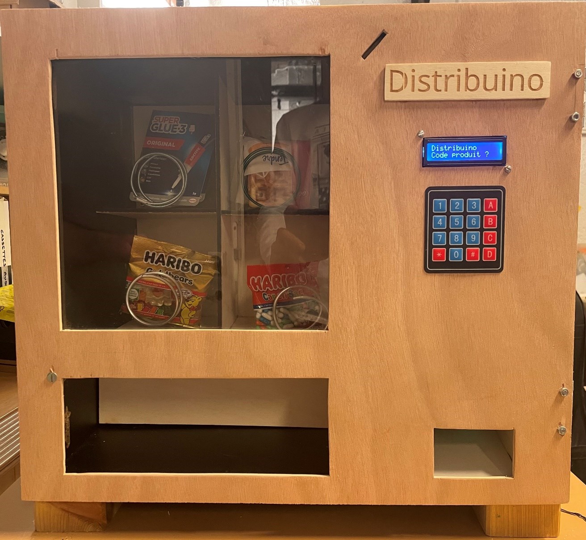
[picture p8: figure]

# Distribuino

# Téo Baillot d’Estivaux

# Evan Galli

## Introduction

Objectif

Faire un distributeur automatique.
Le cahier des charges
- Sélectionner l’article souhaité avec un clavier numérique.
- Afficher les instructions à l’écran.
- Trier les pièces
- Rendre la monnaie.
- Faire tomber l’objet quand l’utilisateur a payé.
Fonctionnement
- L’écran demande dans un premier temps d’entrer le code de l’article souhaité.
- L’utilisateur peut alors entrer un code produit à l’aide du clavier numérique.
- La saisie est affichée en direct sur l’écran (La touche # permet d’effacer la saisie en cas d’erreur et la touche * annule la transaction).
- Lorsque la saisie atteint 3 charactères, le code est vérifié. S’il ne correspond à aucun produit, l’utilisateur devra recommencer la saisie. Sinon, l’écran affiche le prix à payer.
- L’utilisateur insère les pièces dans la fente. Il est possible d’annuler la transaction avec la touche * et la somme versée sera rendue.
- Lorsque le montant de l’article est atteint, le moteur pas à pas de la case correspondant à l’article fait un tour complet afin de faire tomber l’article dans un réceptacle en bas de la porte du distributeur, de sorte que l’utilisateur puisse le récupérer.
- Ensuite, la machine va rendre la monnaie à l’utilisateur.

### Le schéma électrique

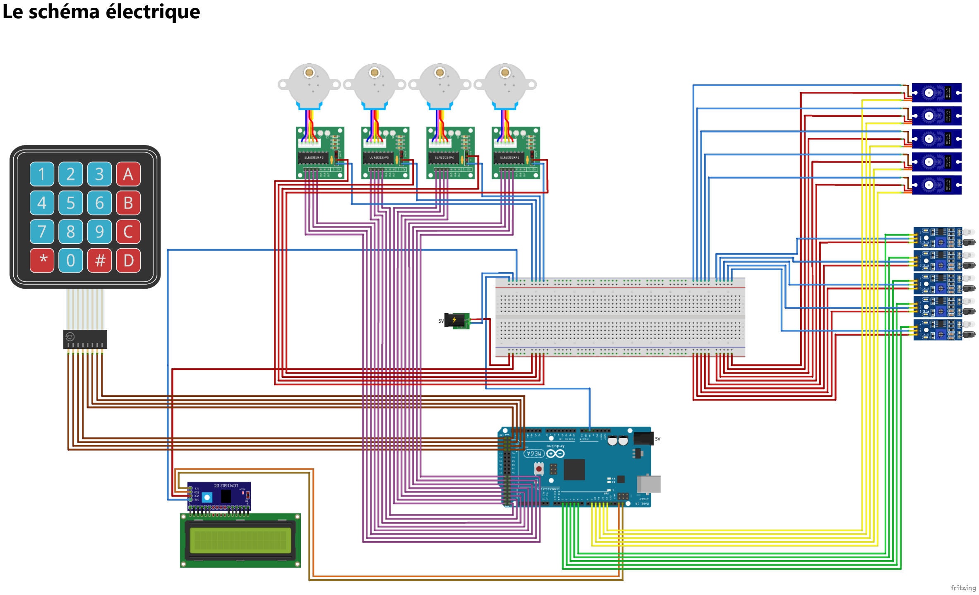
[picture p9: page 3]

### L’algorithme de fonctionnement

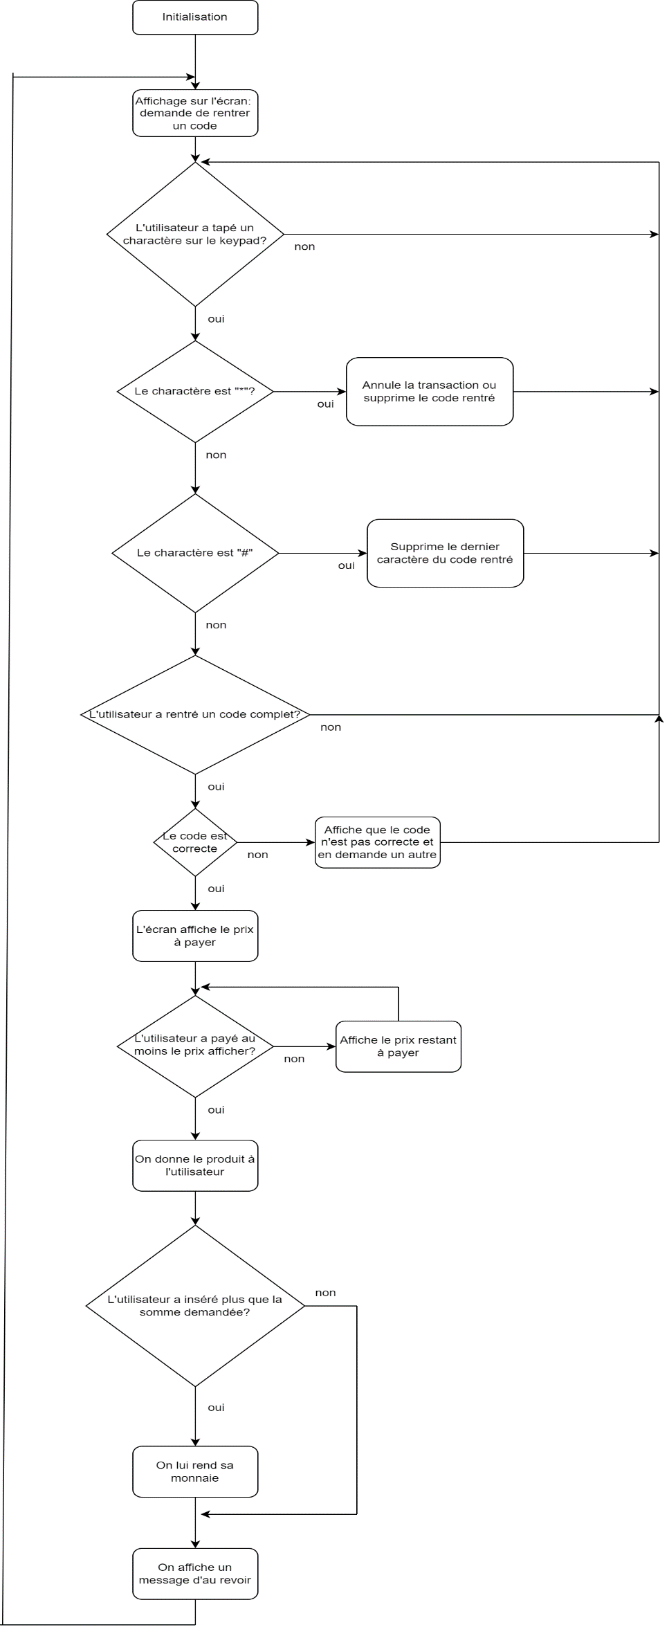
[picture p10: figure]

## Le cout du projet

Le coût du matériel (d’après Amazon)

Produit | Prix
8 plaques de contreplaqué 3mm 30*21cm | 18 euros
4 plaques de contreplaqué 5mm 30*50cm Dont 2 achetés nous-même | 40 euros
3 plaques d’aggloméré | 60 euros
2kg de filament pour imprimante 3D | 50 euros
2 charnières en fond propre | 5 euros
3 tubes de colle forte en fond propre | 9 euros
2 paquets de câbles Dont 1 en fond propre | 16 euros
5 servo-moteurs | 16 euros
7 capteurs infrarouges | 10 euros
Ecran LED | 5 euros
Clavier numérique 4x4 touches | 5 euros
4 moteurs pas-à-pas | 16 euros
Plexiglass | 5 euros
8 équerres | 5 euros
Carte Arduino méga | 20 euros
Total | 280 euros dont les fonds propres

Le coût d’ingénieur

On a travaillé à nous deux 131 heures sur le projet ce qui représente 3111,25 euros pour un salaire brut annuel de 38k euros pour 1600 heures de travail

## Planning

Le planning initial

N° de séance | Evan | Téo
1 | Système de tri des pièces | Stockage des pièces (en vue d'une future capacité à les récupérer)
2 | Détection de la valeur des pièces | Récupération de pièce d'une valeur donné
3 | Réception des pièces et bac qui rend la monnaie | Finition des tâches commencées en séance 1 et 2
4 | Digicode et écran | Faire tomber les objets

5 Schéma de la conception globale et réalisation d'une maquette

6 | Conception de la "carcasse" avec les trous pour les composants | Conception de la porte et du bac de réception
7 | Montage de l'écran, du digicode et du système de pousse des objets | Montage du système de tri et rendu

8 Finition du projet, décoration, ajout de bandes LED, derniers ajustements et tests intensifs

Le planning final

N° de séance | Evan | Téo
1 | Désassemblage d’un ancien projet et fonctionnement des moteurs pas-à-pas | Système de trie des pièces et rendu de la monnaie (modélisation 3D)
2 Fonctionnement de l’écran | | Modélisation 3D du système de trie et de
| Fonctionnement du clavier numérique | rendu des pièces 3

4 Gestion des articles

5 Détection des pièces | | Modélisation 3D du système de trie et de rendu des pièces et début du nouveau trieur de pièces
6 Assemblage du trieur | | Assemblage du trieur et modélisation 3D et découpes laser de pièces pour le trieur de pièces
7 | Fabrication de la boîte, assemblage des cases pour les articles, et suite de l’assemblage du trieur de pièces | Modélisations 3D et découpes lasers pour le trieur et assemblage du trieur
8 | Test des capteurs infrarouges et des servo-moteurs, fin de l’assemblage des cases pour les articles | Découpe laser de la porte + rampe de rendu+ séparations pour trier les pièces+ plexiglass, découpe des « pieds » du distributeur, assemblage de la porte, des « pieds », du trieur de pièces
Bonus | 2 e version de la porte, amélioration du système de rendu et de détection des pièces, assemblage et câblage du distributeur, multiples tests

## Les problèmes qu’on a rencontrés

- La modélisation 3D du système de tri et de rendu des pièces était trop grande donc on a dû l’imprimer en deux parties sauf que la partie du bas contenait beaucoup de supports qui avaient fondus et qui étaient donc aussi durs que la modélisation donc impossible à enlever. On a eu le même problème pour la partie du haut mais en plus j’avais commis une erreur de cotation donc on ne pouvait pas exploiter la modélisation 3D. On a donc refait une autre version du trieur mais cette fois si avec une partie en bois et une partie en impression 3D.
- On a rencontré des problèmes lors de l’assemblage du trieur car on devait assembler toutes les parties du trieur avec une grande précision qui était très dure à avoir. Lorsqu’on n’arrivait pas à avoir la précision nécessaire on rattrapait l’écart en faisant une modélisation 3D comme pour les tubes qu’on n’a pasréussi à coller parfaitement droit donc il y avait un écart entre la valeur théorique de la hauteur des supports qu’on devait avoir et la valeur qu’on avait en pratique.
- Nous avions trop de câbles à brancher sur l’Arduino méga, j'ai donc dû réduire leur nombre. Pour cela, j'ai utilisé un module HW-061 pour brancher l'écran, ce qui m'as permis de gagner 6 pins sur la carte, ce qui est suffisant pour tout brancher.
- Au fur et à mesure que je branchais des composants, l'ampérage nécessaire au fonctionnement des éléments était supérieur aux 500mA que peut délivrer la carte Arduino. Xavier m'as donc dit qu'il fallait procurer 2 alimentations au système, une pour l’Arduino (l'intelligence), une pour les composants (la force).

## Conclusion-perspectives

On a réussi à assembler complétement le distributeur, le distributeur arrive à faire tomber les objets, l’interaction avec l’utilisateur grâce au clavier numérique et à l’écran fonctionne correctement. Cependant, le trieur de pièces fonctionne à quelques exceptions près : on a du mal à rendre les pièces de 10 centimes. Si on avait 9 séances en plus, on aurait probablement refait le trieur de pièce d’une autre façon pour qu’il fonctionne mieux, on aurait rajouté des LED pour faire l’éclairage et améliorer le design. On aurait aussi put faire un système qui nous envoie une notification si en fonction de l’état du tube (si le tube est pleins par exemple). Enfin, on aurait pu mettre des haut-parleurs pour guider les utilisateurs à l’aide d’une commande vocale et peut-être permettre aux utilisateurs malvoyants d’utiliser le distributeur.

## Bibliographie

Les liens utilisés concernent la documentation des composants et des librairies

- https://pdf1.alldatasheet.com/datasheet-pdf/view/470261/TOSHIBA/ULN2003APG.html
- http://www.airspayce.com/mikem/arduino/AccelStepper/
- https://arduinogetstarted.com/tutorials/arduino-keypad
- https://www.arduino.cc/reference/en/libraries/liquidcrystal/
- https://github.com/lucasmaziero/LiquidCrystal_I2C
- https://docs.arduino.cc/learn/electronics/servo-motors
- https://www.arduino.cc/reference/en/libraries/dictionary/

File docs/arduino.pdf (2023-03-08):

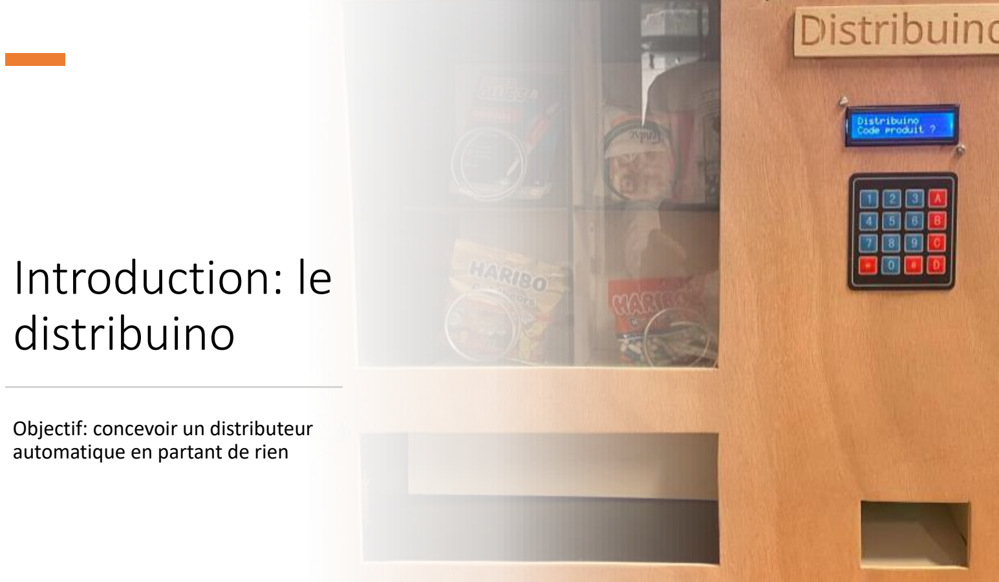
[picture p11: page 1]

# Introduction: le distribuino

Objectif: concevoir un distributeur automatique en partant de rien

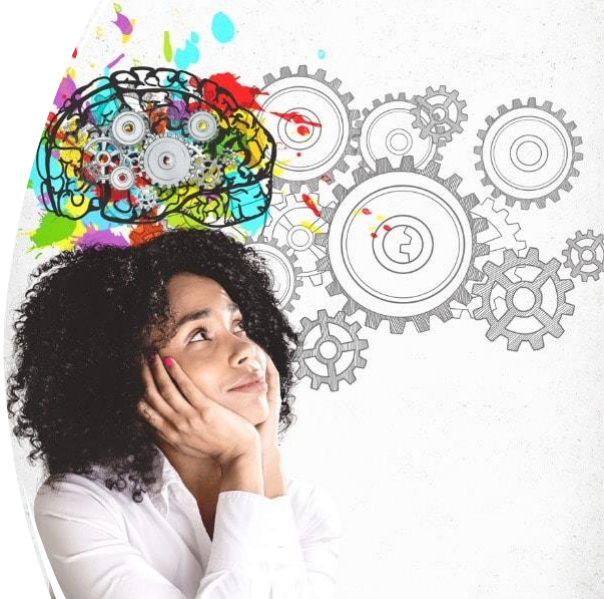
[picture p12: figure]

# De l’idée à la réalisation

### Division du projet en deux grandes parties:

- Fonctionnement global et interactions avec l’utilisateur.
- Gestion du trie des pièces et du rendu de la monnaie.

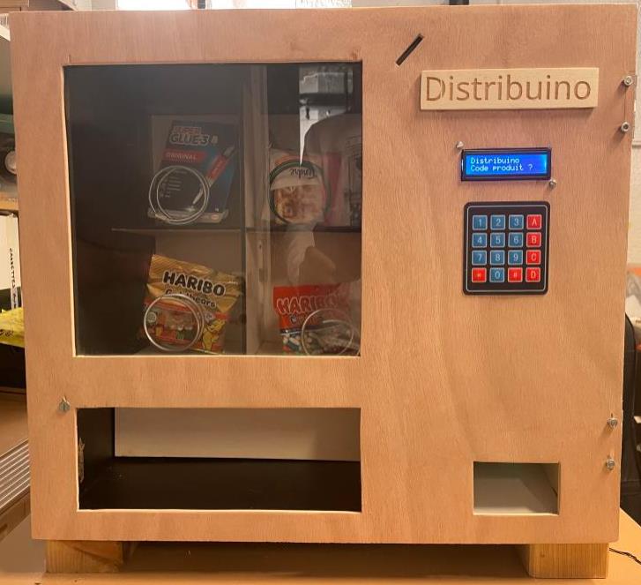
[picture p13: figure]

# La porte :

- Ecran pour informer l’utilisateur.
- Keypad pour permettre à l’utilisateur de communiquer avec la machine.

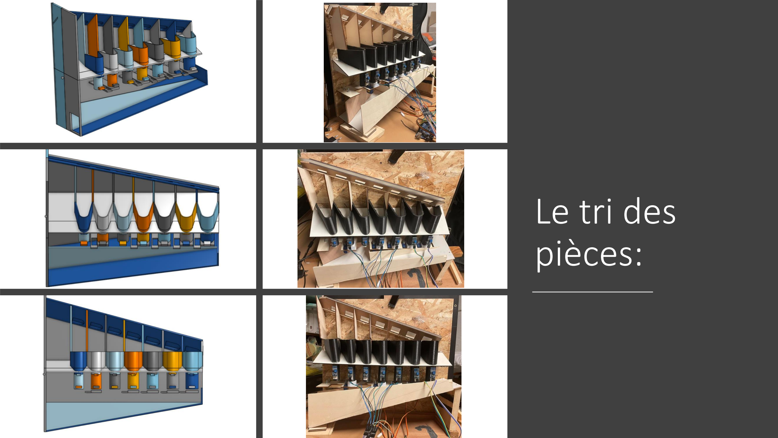
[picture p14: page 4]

# Le tri des pièces:

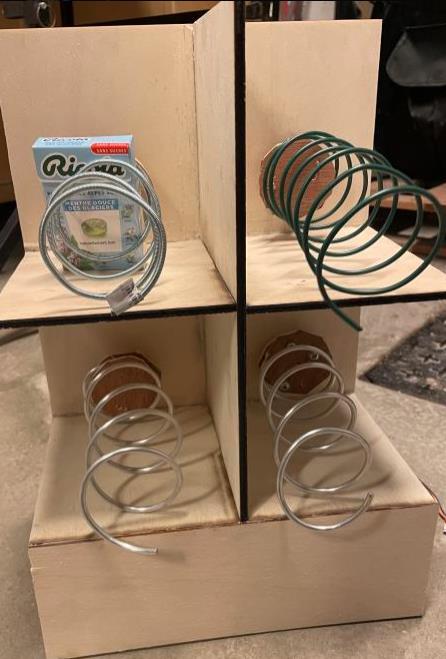
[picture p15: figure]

# Donner le produit à l’utilisateur:

- Vérification du montant inséré.
- Les moteurs pas-à-pas font tomber l’objet si le montant demandé est inséré.
- Calcul du montant à rendre.

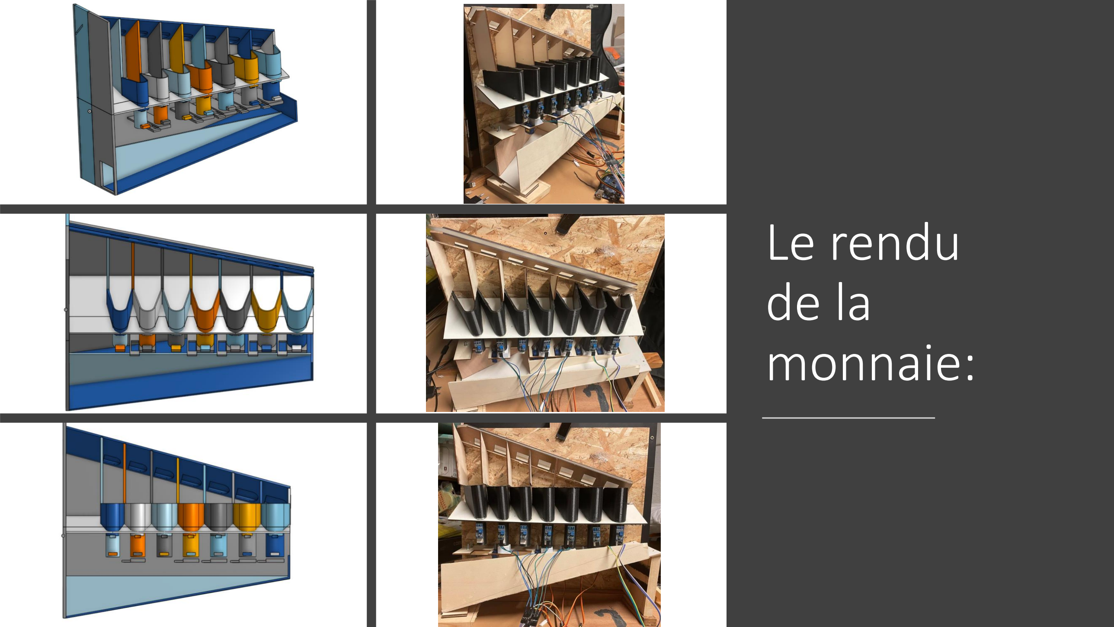
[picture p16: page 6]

# Le rendu de la monnaie:

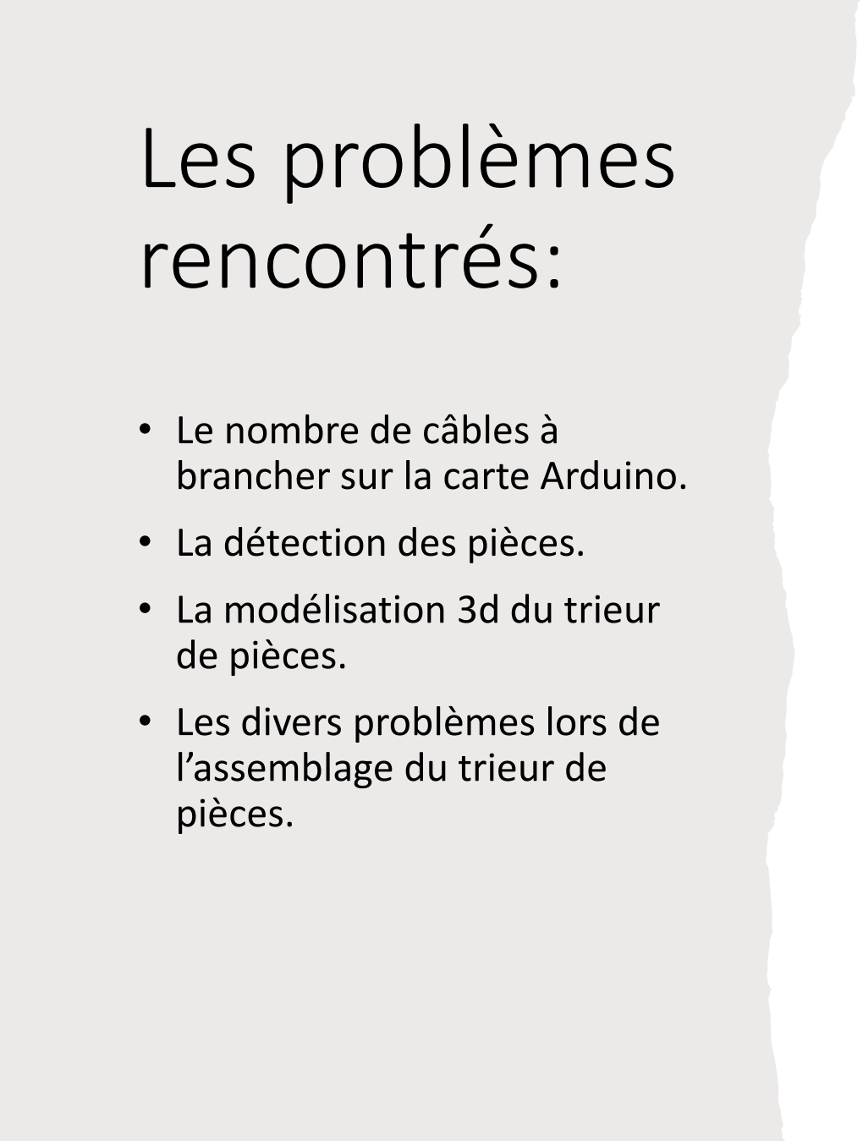
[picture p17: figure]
Les problèmes rencontrés:; • Le nombre de câbles à brancher sur la carte Arduino.; • La détection des pièces.; • La modélisation 3d du trieur de pièces.; • Les divers problèmes lors de l’assemblage du trieur de pièces.
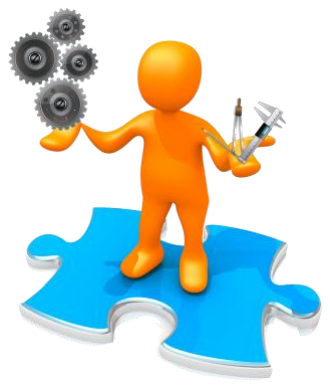
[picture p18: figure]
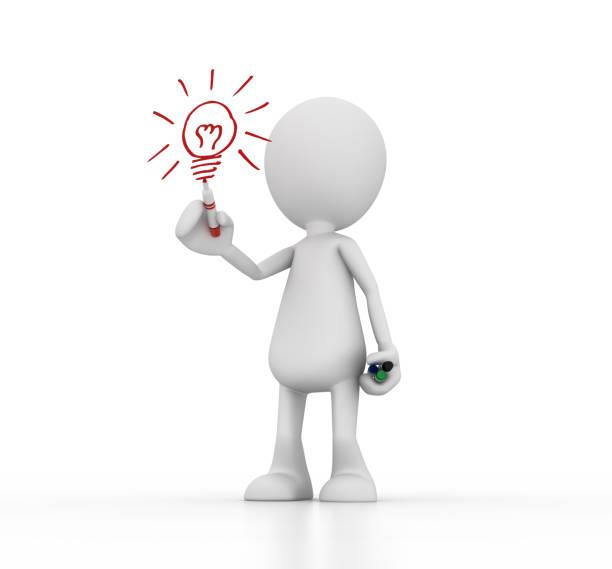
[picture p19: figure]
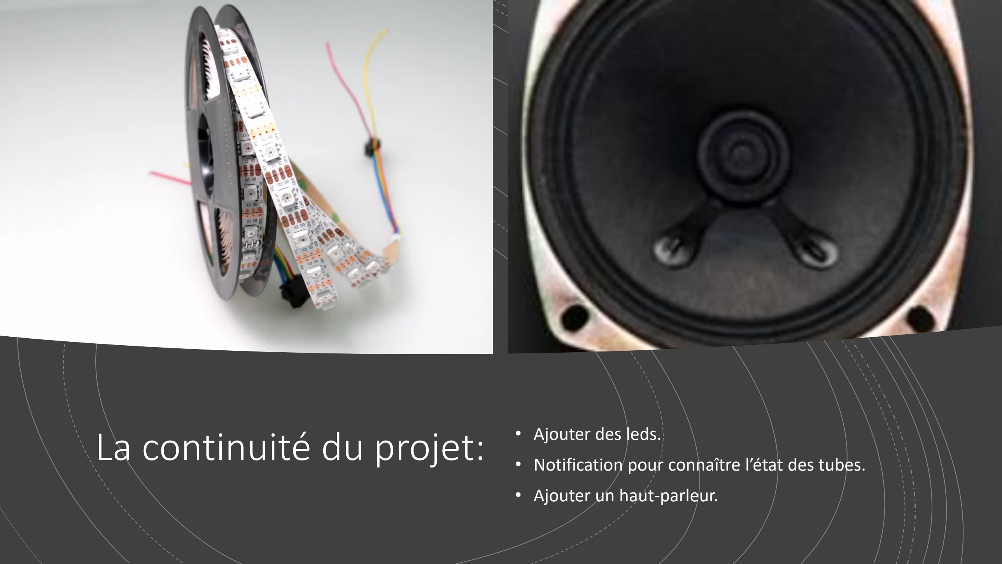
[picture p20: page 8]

La continuité du projet: • Ajouter des leds.
- Notification pour connaître l’état des tubes.
- Ajouter un haut-parleur.

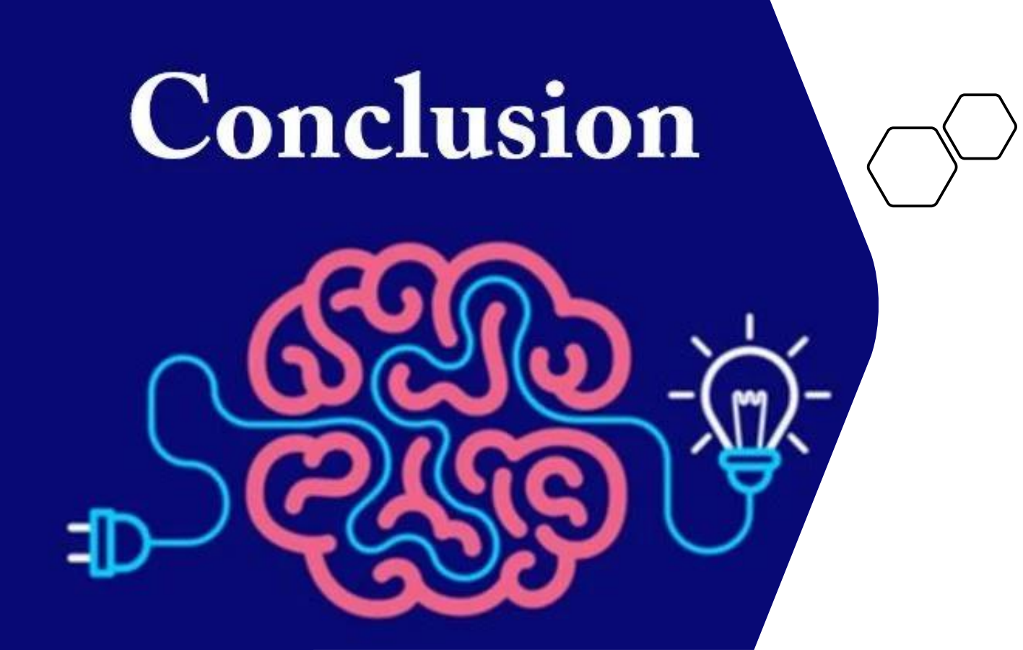
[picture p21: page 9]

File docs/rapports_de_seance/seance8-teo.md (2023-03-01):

#  Séance 8 Téo Baillot d'Estivaux :  

On a décidé de travailler entre la séance dernière et cette dernière séance car nous n'étions clairement pas capables de rendre le projet dans les temps à cause du système de rendu des pièces qui continue de nous poser problème.  

On a fait beaucoup de tests sur le système de trie de pièce qui ont été peu concluants et m'ont poussé à changer des choses pour le faire fonctionner correctement et on a aussi avancé la construction générale de notre projet.  

## Les découpes :  

J'ai fait les découpes laser de la face avant de notre distributeur qui est faite en deux parties qui seront collées car les dimensions étaient trop grandes pour la découpe laser, on a décidé de faire une gravure avec le nom de notre projet et on a mis un espace pour accueillir l'écran, un trou pour les files du digipad, un trou pour insérer les pièces et un trou pour récupérer la monnaie :  

  

  

J'ai ensuite découpé le plexiglace de la dimension souhaitée et ai tout assemblé ensemble :  

  

Puis, j'ai fixé la porte avec des charnières et rajouté un aimant pour pouvoir garder la porte fermée :  

  

Après avoir fait des tests, on s'est rendu compte que certaines pièces ne se triaient pas correctement à cause de la hauteur depuis laquelle elles tombent donc j'ai fait des séparations en bois pour essayer de mieux guider les pièces ce qui a amélioré les choses mais pas complètement réglé le problème donc j'ai dû coller un film plastique pour éviter que les pièces sortent par l'avant.  

  

  

  

Puis, j'ai fait des découpes pour rendre la face avant plus jolie, elle est passé de ça :  



A ça :  

  

Par la suite j'ai aussi fait une découpe laser pour cacher le vide qu'il y a sous la partie qui permet de faire tomber les objets :  

  

Ensuite, j'ai fait des pieds à notre distributeur afin de le surélever un peu du sol pour le rendre plus jolie et de pouvoir le transporter correctement :  



  

  

 Enfin, j'ai découpé des rectangles que j'ai assemblé afin de faire un espace pour que l'utilisateur puisse récupérer sa monnaie sans qu'elle tombe par terre :  
 
   

## Les tests :  

On a fait beaucoup de test sur le système de trie des pièces et on a rencontré beaucoup de problèmes.  

Tout d'abord, comme les tubes ont été collés sur une planche un par un, le problème a été qu'ils n'arrivaient pas à la hauteur théorique calculée donc j'ai dû refaire des supports qui retiennent les pièces et la partie haute de certains servo-moteurs pour ajuster cet écart qui doit être très précis (1.5 fois l'épaisseur d'une pièce) pour fonctionner correctement.  
Le problème a aussi été que la planche de bois sur laquelle j'ai fixé les tubes et la planche de bois sur laquelle j'ai collé les supports n'étaient pas parfaitement droites ce qui a créé encore plus d'imprécisions.

  

On s'est aussi rendu compte en testant que le tube des pièces de 10 centimes n'était pas parfaitement lisse à l'intérieur donc j'ai dû démonter le trieur pour le limer pour que les pièces puissent passer correctement et le remonter.  

De plus, un des servo-moteurs que j'avais fixé ne marchait pas donc j'ai dû démonter une nouvelle fois le trieur pour le changer et le remonter.  

On s'est aperçu en déplaçant la boîte qu'il y avait des visses qui dépassaient dessous donc j'ai utilisé la lime et une scie à métaux pour les enlevées pour éviter qu'on se fasse mal sans faire attention. J'en ai aussi profité pour raccourcir les visses qui dépassaient de la face avant.  

  

Par la suite, j'ai fait une rampe pour rendre les pièces, mais la pente était trop faible pour faire glisser les pièces donc j'ai dû en faire une autre qui puisse arriver au-dessus du bas des servo-moteurs et dans une matière qui glisse mieux. J'ai donc collé un autocollant qui permet aux pièces de mieux glisser sur la nouvelle rampe et fait des guides pour que la pièce ne sorte pas de la rampe :  

  

  

   

De plus, Evan s'est rendu compte en testant les capteurs infrarouges qu'ils ne marchaient pas probablement parcequ'ils étaient trop loin des tubes, j'ai donc limer toutes les surfaces sur lesquelles on avait coller les capteurs afin qu'ils soient plus proches du tube :  

  

Par la suite, en faisant des tests Evan s'est rendu compte qu'on aurait besoin d'une alimentation 5V donc j'en ai pris une et je l'ai adaptée pour pouvoir y mettre un adaptateur pour l'arduino:  



## Conclusion :  

Nous sommes assez content de nous et de notre projet même s'il ne fonctionnait par parfaitement à la fin de la séance mais on va essayer de le finir chez nous. On a tout de même fait face à de nombreux problèmes tout au long du projet mais nous n'avons pas baissé les bras et sommes resté motivé à trouver une solution à chacun des problèmes. On a ainsi appris beaucoup de choses et en particulier qu'il est très difficile de respecter le planning des choses que l'on doit faire.

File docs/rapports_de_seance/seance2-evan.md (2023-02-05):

# Evan

## Séance 2 : 4 janvier 2023

### Branchement de l'écran

J'ai récuperé un écran LCD 16x2 (modèle *1602A*) sur le précédant projet de distributeur

J'ai effectué les branchements suivants :

| Pin sur l'Arduino | Pin sur l'écran | Pin sur le potentiomètre 10K |
|:---:|:---:|:---:|
| 5V | VDD<br>A | |
| GND | VSS<br>RW<br>K  | Gauche |
| | V0 | Centre |
| 7 | RS | |
| 8 | E | |
| 9 | D4 | |
| 10 | D5 | |
| 11 | D6 | |
| 12 | D7 | |



Le potentiomètre permet de régler le contraste de l'écran.

https://user-images.githubusercontent.com/24252743/210729041-f911d8b1-f771-4000-8fe1-7024fb148205.mp4

### Premiers tests d'affichage

J'ai tout d'abord souhaité écrire un simple texte sur l'écran, pour celà, j'ai utilisé la bibliothèque [LiquidCrystal](https://www.arduino.cc/reference/en/libraries/liquidcrystal/)

```cpp
#include <LiquidCrystal.h>

LiquidCrystal lcd(7, 8, 9, 10, 11 , 12);

void setup() {
  lcd.begin(16, 2);
  lcd.setCursor(0, 0);
  lcd.write("Distribuino v0");
}

void loop() {
}
```

Puis, j'ai ajouté un effet de scrolling du texte pour pouvoir afficher de plus longues phrases

```cpp
#include <LiquidCrystal.h>

LiquidCrystal lcd(7, 8, 9, 10, 11 , 12);

void setup() {
  lcd.begin(16, 2);
}

void loop() {
  writeToScreenAndAutoScroll(0, "Distribuino v0");
  writeToScreenAndAutoScroll(1, "Veuillez entrer le code du produit souhaite");
}

void writeToScreenAndAutoScroll(int line, String text) {
  int textLength = text.length()+1;
  char str1[textLength];
  text.toCharArray(str1, textLength);
  
  for (int j = 0; j < max(1, textLength - 16); j++) {
    for(int i = 0; i < 16; i++){
      lcd.setCursor(i, line);
      if(i+j < textLength -1) lcd.write(str1[i+j]);
      else lcd.write(" ");
    }
    delay(500);
  }
}
```

https://user-images.githubusercontent.com/24252743/210729169-198bbead-360d-43c5-a217-ae5832e5f0bd.mp4

Constatant que l'écran "sintillait" lors de la réécriture du texte, ce qui est assez génant à la lecture, j'ai modifié mon programme pour afficher sur une meme ligne plusieurs bouts de phrases alternativements.

```cpp
#include <LiquidCrystal.h>

LiquidCrystal lcd(7, 8, 9, 10, 11 , 12);

void setup() {
  lcd.begin(16, 2);
}

void loop() {
  String line0[] = {"Distribuino v0"};
  String line1[] = {"Veuillez entrer", "le code du", "produit souhaite"};
  writeToScreenAndAutoScroll(0, line0, 1);
  writeToScreenAndAutoScroll(1, line1, 3);
}

void writeToScreenAndAutoScroll(int line, String lines[], int lineNumber) {
  for(int j = 0; j < lineNumber; j++){
    String text = lines[j];
    int textLength = text.length()+1;
    char str1[textLength];
    text.toCharArray(str1, textLength);
  
    for(int i = 0; i < 16; i++){
      lcd.setCursor(i, line);
      lcd.write(" ");
    }
    
    lcd.setCursor(0, line);
    lcd.write(str1);
    delay(1500);
  }
}
```

https://user-images.githubusercontent.com/24252743/210720415-fd54bd8f-45fb-428e-b372-571b7d39c32a.mp4

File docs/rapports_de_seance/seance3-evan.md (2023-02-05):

# Evan

## Séance 3 : 11 janvier 2023

### Branchement du clavier numérique

Un clavier numérique 4x4 nous avait été fourni lors de la première séance.  
Le clavier se branche avec 8 fils : 4 pour les colonnes, 4 pour les lignes. 
La combinaison des deux permettant de déterminer la touche enfoncée.



### Simple test du clavier

Pour récuprer la valeur de la touche enfoncé, j'ai utilisé la librairie [Keypad](https://playground.arduino.cc/Code/Keypad/)

Dans un premier temps, j'ai fait en sorte que la valeur de la touche enfoncé soit affichée dans le moniteur série

```cpp
#include <Keypad.h>

const int ROW_NUM = 4; //four rows
const int COLUMN_NUM = 4; //four columns

char keys[ROW_NUM][COLUMN_NUM] = {
  {'1','2','3', 'A'},
  {'4','5','6', 'B'},
  {'7','8','9', 'C'},
  {'*','0','#', 'D'}
};

byte pin_rows[ROW_NUM] = {9, 8, 7, 6}; //connect to the row pinouts of the keypad
byte pin_column[COLUMN_NUM] = {5, 4, 3, 2}; //connect to the column pinouts of the keypad

Keypad keypad = Keypad( makeKeymap(keys), pin_rows, pin_column, ROW_NUM, COLUMN_NUM );

void setup(){
  Serial.begin(9600);
}

void loop(){
  char key = keypad.getKey();

  if (key){
    Serial.println(key);
  }
}
```

https://user-images.githubusercontent.com/24252743/211828880-aedc92f8-2ee3-4201-900f-da736e63023e.mp4

### Branchements plus poussés en utilisant le travail effectué lors des séances précédentes

J'ai souhaité que la saisit s'affiche directement à l'écran.  
Comme l'arduino Uno ne disposait pas de suffisament de PINs, j'ai récupéré une Arduino Mega 2560 qui m'a permis d'effectuer tout les branchements necessaires sur les PINs 30 à 35 pour l'écran et 46 à 53 pour le clavier numérique.  
Dans mon code, j'ai limitée la saisie à une taille de 4 caractères, ce qui est amplement suffisant pour notre projet.  
J'ai aussi permis que l'on puisse annuler la saisie en appuyant sur les touches `*` ou `#`

```cpp
#include <Keypad.h>
#include <LiquidCrystal.h>

const int ROW_NUM = 4; //four rows
const int COLUMN_NUM = 4; //four columns
char keys[ROW_NUM][COLUMN_NUM] = {
  {'1','2','3', 'A'},
  {'4','5','6', 'B'},
  {'7','8','9', 'C'},
  {'*','0','#', 'D'}
};
byte pin_rows[ROW_NUM] = {47, 49, 51, 53}; //connect to the row pinouts of the keypad
byte pin_column[COLUMN_NUM] = {46, 48, 50, 52}; //connect to the column pinouts of the keypad
Keypad keypad = Keypad(makeKeymap(keys), pin_rows, pin_column, ROW_NUM, COLUMN_NUM);

LiquidCrystal lcd(31, 33, 35, 30, 32, 34);

const int codeLength = 4;
String productCode = "";

void setup(){
  Serial.begin(9600);
  lcd.begin(16, 2);
}

void loop(){
  char key = keypad.getKey();

  if (key) {
    if(key == '*' | key == '#') productCode = ""; // Cancel
    else if(productCode.length() < codeLength) productCode += key;
  }
  
  writeToScreen(0, "Distribuino v0");
  if(productCode == "") writeToScreen(1, "Code produit ?");
  else writeToScreen(1, productCode);
}

void writeToScreen(int line, String text) {
  // Clear the screen line
  for(int i = 0; i < 16; i++){
    lcd.setCursor(i, line);
    lcd.write(" ");
  }
    
  lcd.setCursor(0, line);
  lcd.print(text);
}
```

IMG_E9460

En suite, j'ai branché un moteur pas à pas sur les PINs PWM tel que spécifié sur [le rapport de la séance 1](seance1-evan.md).  
Et j'ai fait en sorte que le moteur pas à pas effectue une rotation complète (360°) lorsque le code produit est entré (il n'y a, pour le moment, pas de vérification du code saisit, ni de demande de paiement)

```cpp
#include <Keypad.h>
#include <LiquidCrystal.h>
#include <Stepper.h>

const int ROW_NUM = 4; //four rows
const int COLUMN_NUM = 4; //four columns
char keys[ROW_NUM][COLUMN_NUM] = {
  {'1','2','3', 'A'},
  {'4','5','6', 'B'},
  {'7','8','9', 'C'},
  {'*','0','#', 'D'}
};
byte pin_rows[ROW_NUM] = {47, 49, 51, 53}; //connect to the row pinouts of the keypad
byte pin_column[COLUMN_NUM] = {46, 48, 50, 52}; //connect to the column pinouts of the keypad
Keypad keypad = Keypad(makeKeymap(keys), pin_rows, pin_column, ROW_NUM, COLUMN_NUM);

LiquidCrystal lcd(31, 33, 35, 30, 32, 34);

const int stepsPerRevolution = 2048;
const int rpm = 16;
Stepper stepper1 = Stepper(stepsPerRevolution, 8, 10, 9, 11);

const int codeLength = 4;
String productCode = "";

void setup(){
  Serial.begin(9600);
  lcd.begin(16, 2);
  stepper1.setSpeed(rpm);
}

void loop(){
  char key = keypad.getKey();

  if (key) {
    if(key == '*' | key == '#') productCode = ""; // Cancel
    else if(productCode.length() < codeLength) productCode += key;
  }
  
  writeToScreen(0, "Distribuino v0.3");
  if(productCode == "") writeToScreen(1, "Code produit ?");
  else if(productCode.length() == codeLength) 
  {
    writeToScreen(1, "Distribution...");
    stepper1.step(-stepsPerRevolution);
    productCode = "";
  }
  else writeToScreen(1, productCode);
}

void writeToScreen(int line, String text) {
  // Clears the screen line
  for(int i = 0; i < 16; i++){
    lcd.setCursor(i, line);
    lcd.write(" ");
  }

  // Writes the text
  lcd.setCursor(0, line);
  lcd.print(text);
}
```

IMG_E9463

https://user-images.githubusercontent.com/24252743/211832537-18a13e8d-21fa-4c46-9d62-8e0b3d8797a1.mp4

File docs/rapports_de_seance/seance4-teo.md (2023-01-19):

# Séance 4 Téo Baillot d'Estivaux:
Lors de cette séance j'ai fini la modélisation du trieur de pièce, j'ai fini les plateformes qui permettent de retenir les pièces et placer les servo-moteurs, j'ai rajouté un carré qui décalera le capteur infrarouge du tube pour qu'il ne rentre pas dans le tube, j'ai fait une rampe pour rendre les pièces, et j'ai fait un espace pour que l'utilisateur puisse récupérer la monnaie.  

J'ai aussi pris le temps de vérifier toutes les cotations pour être sûr que la modélisation pourra bien trier les pièces comme on le souhaite.  

Au moment où j'ai demandé à imprimer ma pièce on m'a fait remarquer qu'elle était trop grande de 3 centimètres, j'ai donc dû rester une heure de plus pour faire les changements qu'on m'avait demandé pour que l'impression puisse être faite pendant la semaine de ski. 
Finalement, comme il y avait des trous dans la pièce dans plusieurs sens, j'ai découpé la pièce en deux parties pour que tous les trous puissent s'imprimer correctement.
J'ai donc rendu les fichiers mais ce n'est pas garanti que l'on aura la pièce pour la rentrée car l'impression est assez longue, on devra peut-être donc faire les tests plus tard que prévu ce qui pourrait être gênant si on se rend compte qu'il y a des modifications à faire sur le système de trie.  

Il ne nous reste donc plus qu'à espérer que l'on n'attendra pas trop longtemps que l'impression se fasse et que les tests seront satisfaisants.

## Les plateformes sous les tubes et supports pour les capteurs infrarouges:
  

  

  

  

## La rampe de rendu des pièces:
  

  

  

  

## L'espace de récupération des pièces:
  

## Le rendu final:
  

  

  

  

  



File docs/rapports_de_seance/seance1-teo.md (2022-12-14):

# Séance 1 Téo Baillot d'Estivaux:
Nous avons découvert que notre projet de distributeur automatique avait déjà été fait dans les années précédentes. Comme nous pensions partir de 0, cela a changé notre organisation. On avait décidé de faire une partie de la modélisation pour trier les pièces chacun, mais finalement je vais faire la partie modélisation pour le tri des pièces en entier et le rendu de la monnaie. Je me suis donc posé la question de comment trier les pièces et je me suis dis que le processus se ferait en 3 étapes :
## Etape 1:
Etape1
La première étape consiste à faire un rail qui va trier les pièces. Nous avons décidé que notre distributeur n'accepterait pas les pièces rouges(1 centime,2 centimes,5 centimes) donc je vais faire 7 trous qui seront de plus en plus large de façcon à ce que les pièces soient triées en fonction de leur taille. J'ai donc fait des recherches pour trouver les dimensions correspondant à chaque pièces pour pouvoir déterminer quelle pièce tombera dans quel trou. Le premier trou fera tomber les pièces de 1 et 2 centimes, le deuxième fera tomber les pièces de 10 centimes, le troisième les pièces de 5 centimes, le quatrième les pièces de 20 centimes, le cinquième les pièces de 50 centimes, le sixième les pièces de 1 euro, et le septième les pièces de 2 euros.
## Etape 2:
Etape 2
La seconde étape est de récupérer et renvoyer les pièces. Je vais donc faire un toboggan dans lesquelles les pièces tomberont et glisseront pour tomber dans probablement un cylindre afin de réduire les chances que la pièce se mette n'importe comment dans le cylindre. Les cylindres auront un capteur qui permettra de détecter quand ils sont pleins et auront une encoche en bas qui permettra de faire sortir les pièces une par une.
## Etape 3:
Etape 3
La dernière étape sera de conduire les pièces à la sortie et donc de refaire une sorte de rampe, évidemment les pièces que nous n'acceptons pas tomberont directement dedans.
## Modélisation:
Je me suis donc lancé au cours de cette première séance sur la réalisation de cette première étape, j'ai redécouvert  Onshape, et voici le résultat:





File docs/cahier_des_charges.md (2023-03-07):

Le projet consiste à faire un distributeur de bonbons et de confiseries comme ceux que l'on peut trouver au sein de notre établissement.  

Nous devrons pouvoir :

*	Sélectionner l’article souhaité avec un keypad.
*	Afficher les instructions à l’écran.
*	Trier les pièces 
*	Rendre la monnaie.
*	Faire tomber l’objet quand l’utilisateur a payé.

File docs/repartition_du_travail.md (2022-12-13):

## Séance 1
> Recherche de solutions aux problématiques techniques du tri des pièces 
 
**Evan:** Système de tri des pièces  
**Téo:** Stockage des pièces (en vue d'une future capacité à les récupérer)

## Séance 2
> Continuation du système de tri des pièces

**Evan:** Détection de la valeur des pièces  
**Téo:** Récuperation de pièce d'une valeur donné  

## Séance 3
> Finition du système de tri des pièces

**Evan:** Réception des pièces et bac qui rend la monnaie  
**Téo:** Finition des tâches commencées en séance 1 et 2   

## Séance 4
> Composants

**Evan:** Digicode et écran  
**Téo:** Faire tomber les objets  

## Séance 5
> Démarrage de la conception

**A deux:** Schéma de la conception globale et réalisation d'une maquette

## Séance 6
> Conception de la "carcasse"

**Evan:** Conception de la "carcasse" avec les trous pour les composants  
**Téo:** Conception de la porte et du bac de réception 

## Séance 7
> Assemblage du projet

**Evan:** Montage de l'écran, du digicode et du système de pousse des objets   
**Téo:** Montage du système de tri et rendu   

## Séance 8
> Finitions

**A deux:** Finition du projet, décoration, ajout de bandes LED, derniers ajustements et tests intensifs

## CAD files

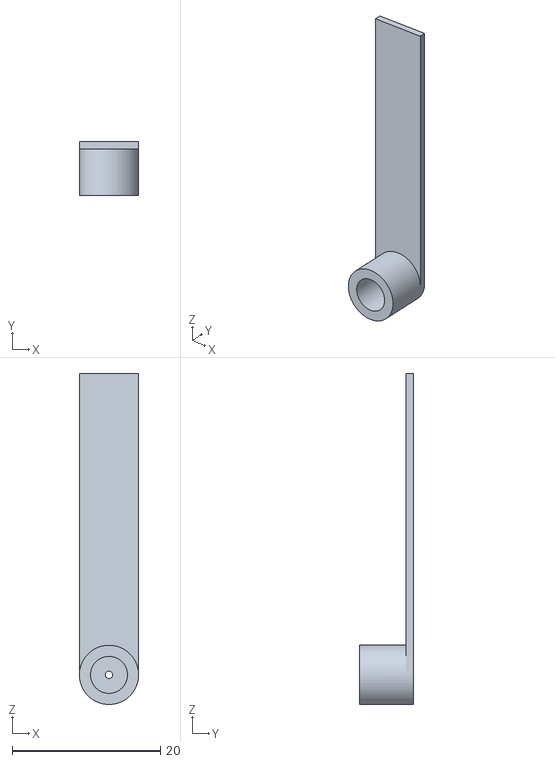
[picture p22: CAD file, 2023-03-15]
decoupes et impressions/2€.stl
8.00 x 7.25 x 44.7

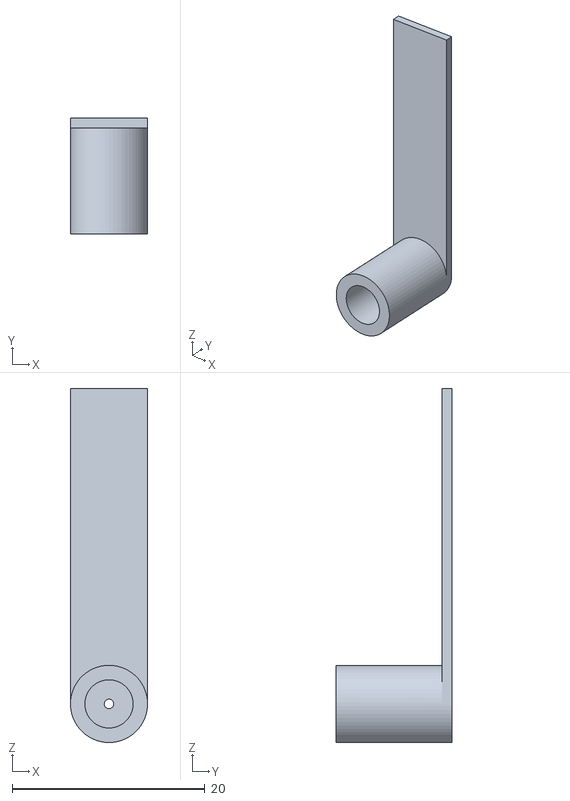
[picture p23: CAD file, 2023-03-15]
decoupes et impressions/10c.stl
8.00 x 12.0 x 36.7

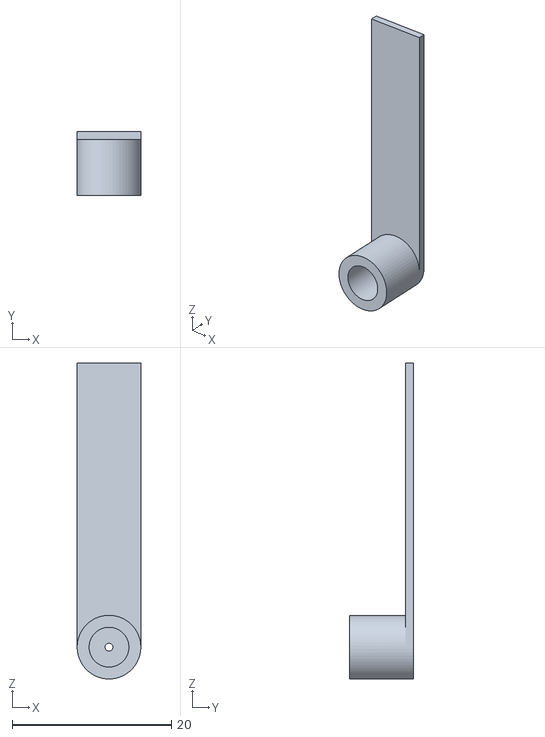
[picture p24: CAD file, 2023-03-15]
decoupes et impressions/1€.stl
8.00 x 8.00 x 39.7

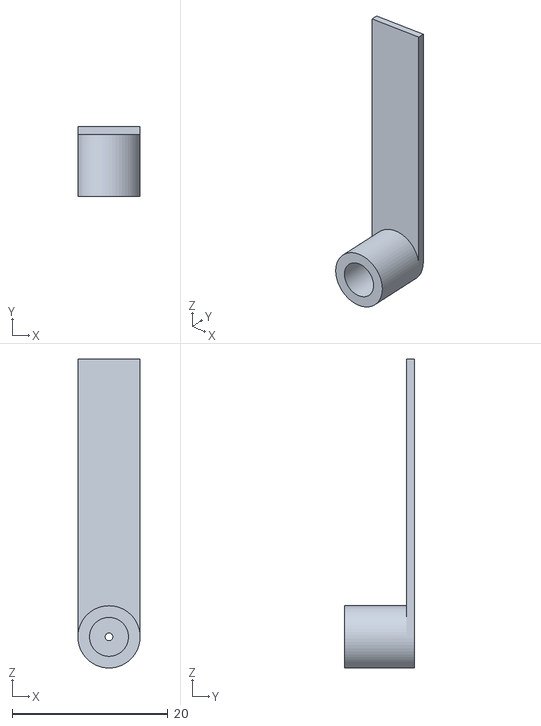
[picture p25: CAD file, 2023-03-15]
decoupes et impressions/20c.stl
8.00 x 9.00 x 39.7

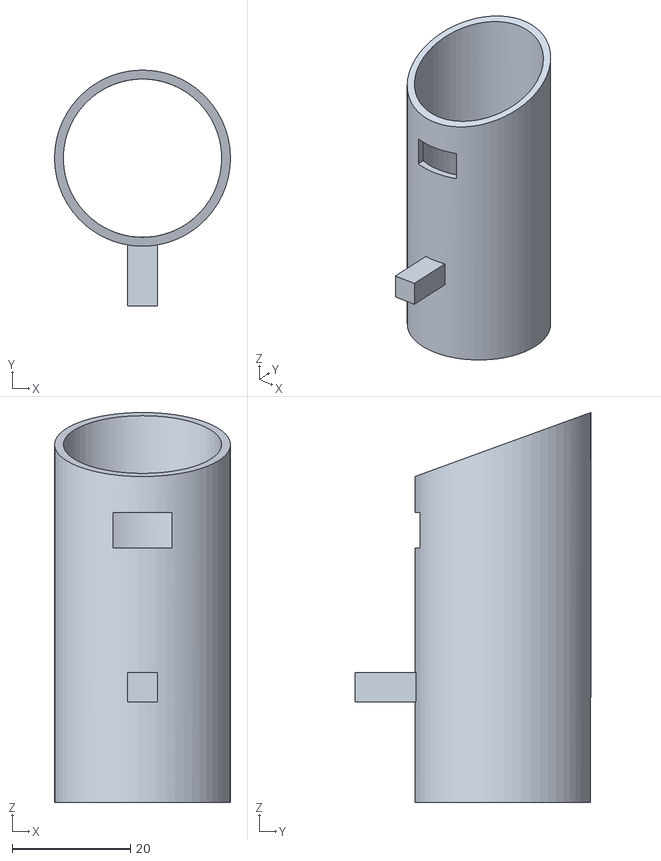
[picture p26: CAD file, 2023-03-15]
decoupes et impressions/tube 2 euros.stl
29.7 x 39.8 x 65.9

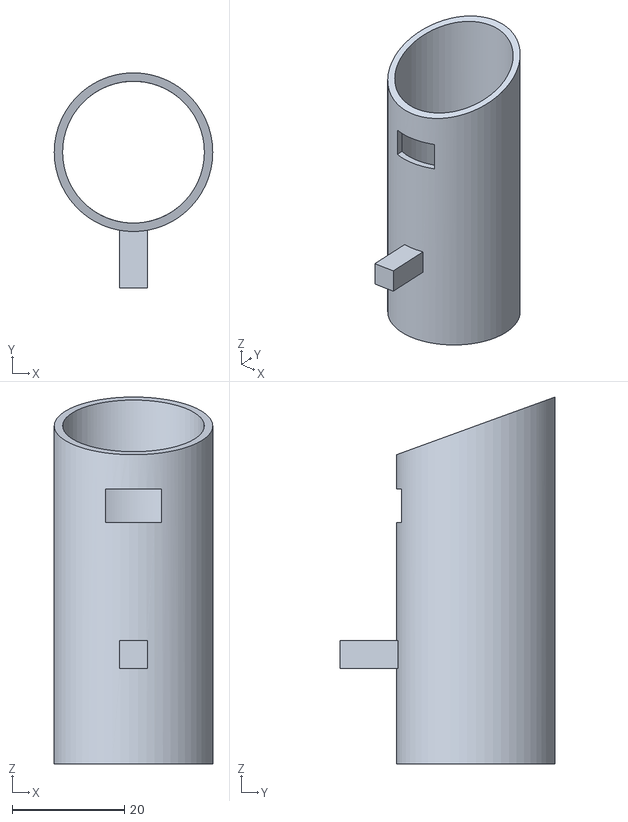
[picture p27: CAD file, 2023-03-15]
decoupes et impressions/tube 50 centimes (1).stl
28.2 x 38.3 x 65.4

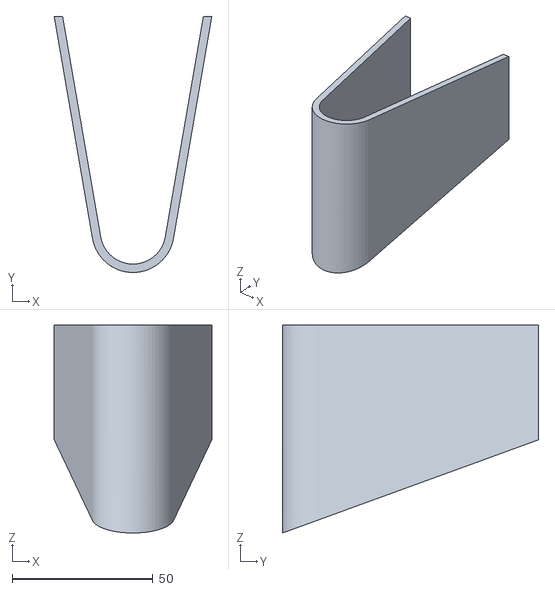
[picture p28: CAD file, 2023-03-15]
decoupes et impressions/guide 20 centimes (1).stl
56.0 x 91.0 x 73.9

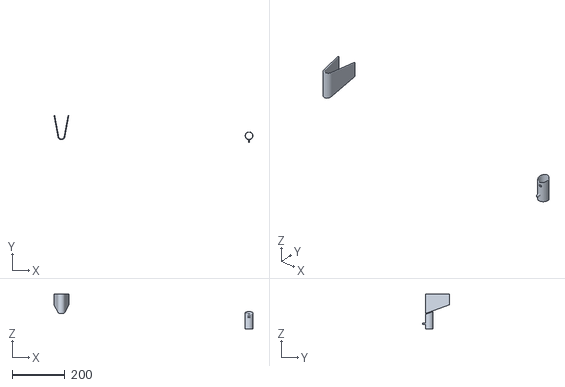
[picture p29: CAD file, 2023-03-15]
decoupes et impressions/guide 10 centimes (1).stl
751.5 x 101.1 x 132.0

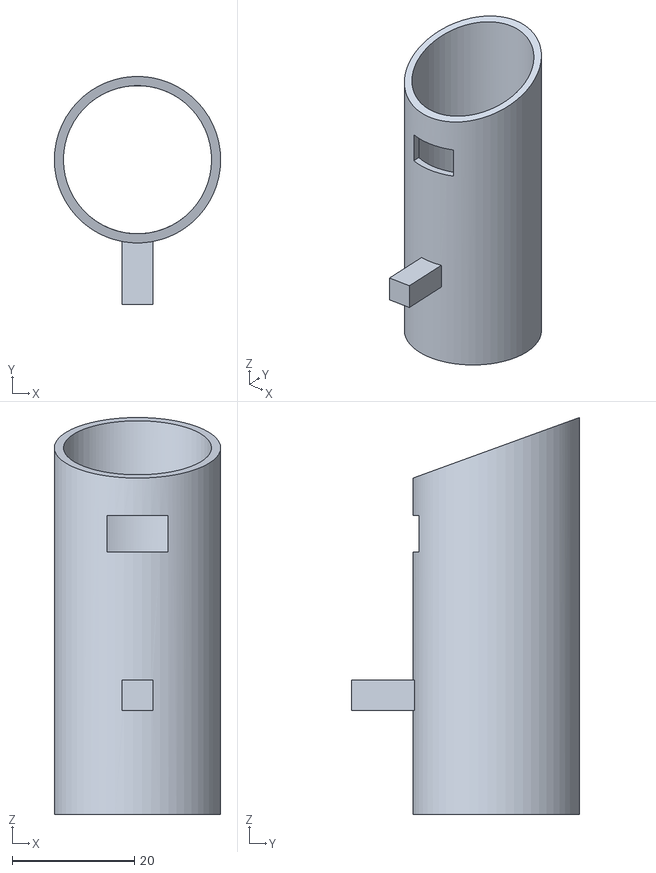
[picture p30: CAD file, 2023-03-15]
decoupes et impressions/tube 1 euro (1).stl
27.2 x 37.3 x 65.0

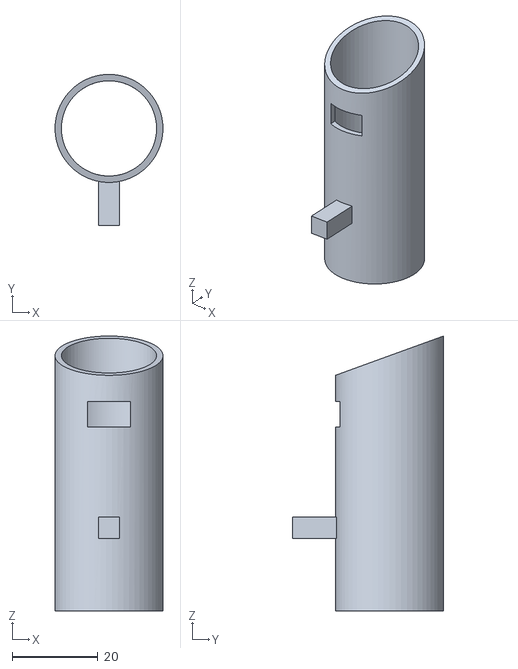
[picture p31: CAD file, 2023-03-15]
decoupes et impressions/tube 5 centimes (1).stl
25.2 x 35.3 x 64.3

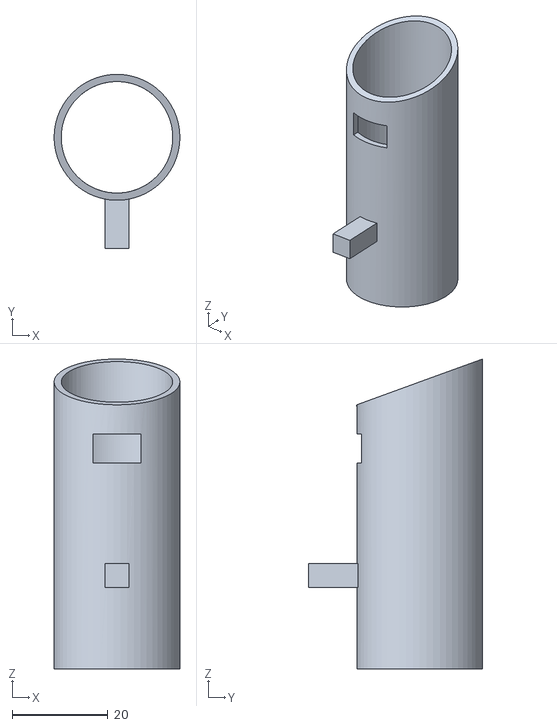
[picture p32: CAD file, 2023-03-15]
decoupes et impressions/tube 20 centimes (1).stl
26.2 x 36.3 x 64.6

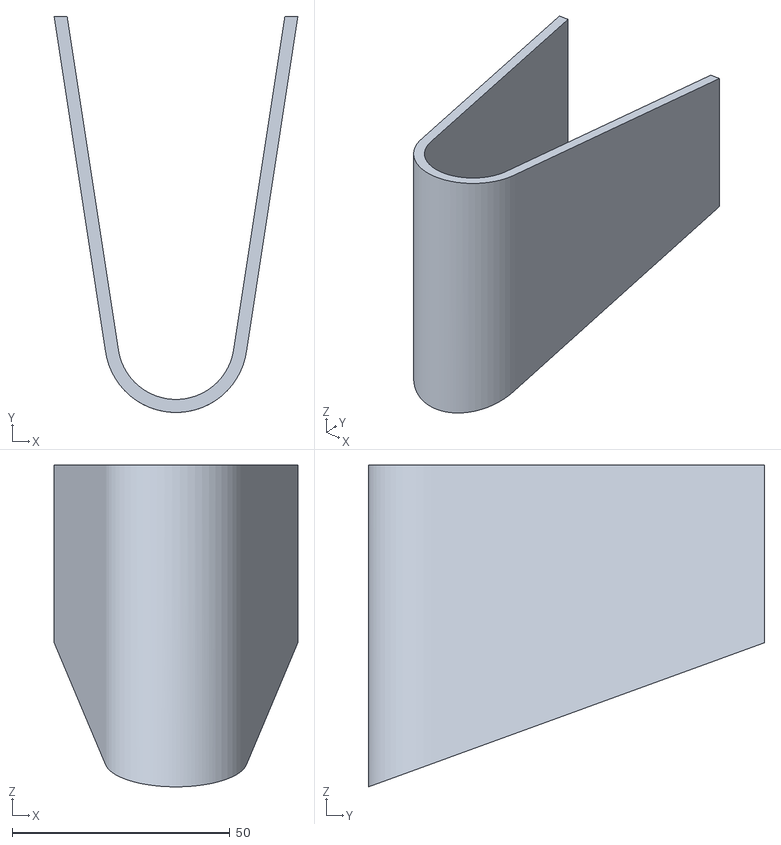
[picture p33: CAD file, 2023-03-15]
decoupes et impressions/guide 2 euros (1).stl
56.0 x 91.0 x 73.9

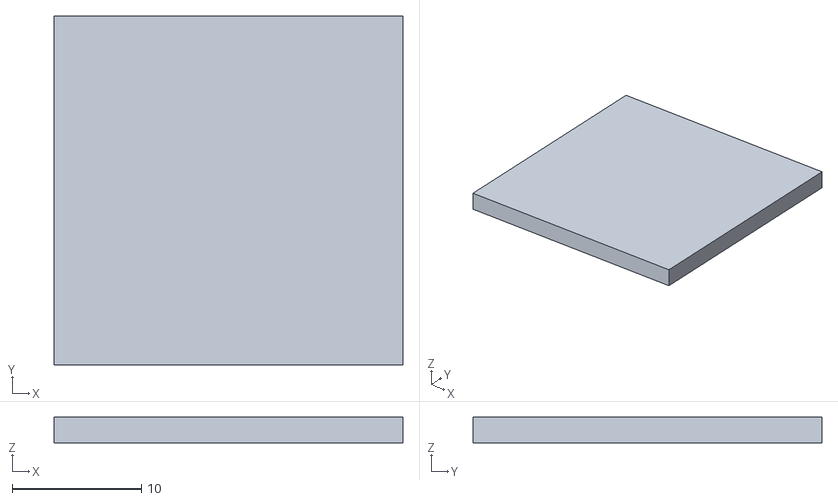
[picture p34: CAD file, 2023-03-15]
decoupes et impressions/support 50 centimes (1).stl
27.0 x 27.0 x 2.00

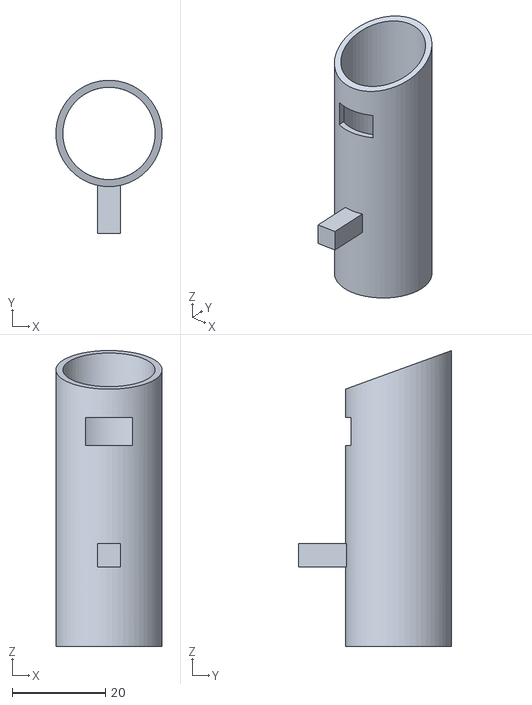
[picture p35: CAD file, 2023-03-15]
decoupes et impressions/tube 2 centimes (1).stl
22.8 x 32.8 x 63.4

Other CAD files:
decoupes et impressions/tube 10 centimes (1).stl
decoupes et impressions/support 1 euro (2).stl
decoupes et impressions/support 10 centimes (2).stl
decoupes et impressions/Systeme de trie des pièces partie haute.stl
decoupes et impressions/Système de trie des pièces partie basse.stl
decoupes et impressions/Système de trie des pièces.stl
decoupes et impressions/guide 1 euro (1).stl
decoupes et impressions/guide 2 centimes (1).stl
decoupes et impressions/guide 5 centimes (1).stl
decoupes et impressions/guide 50 centimes (1).stl

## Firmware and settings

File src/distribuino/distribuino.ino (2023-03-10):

#include <Keypad.h>
#include <LiquidCrystal_I2C.h>
#include <AccelStepper.h>
#include <Servo.h>

struct Item
{
  String itemCode; // Le code à taper
  String itemName; // Le nom du produit
  float itemPrice; // Le prix du produit
  AccelStepper stepper; // Le moteur pas à pas correspondant
};

struct Coin
{
  float coinValue; // La valeur de la pièce
  int captorPin;   // Le numéro du pin sur lequel est branché le capteur infrarouge
  int servoPin;    // Le numéro du pin sur lequel est branché le servo-moteur
};


const int codeLength = 3; // La taille des codes produits

const int ROW_NUM = 4;    // Nombre de lignes du keypad
const int COLUMN_NUM = 4; // Nombre de colonne
char keys[ROW_NUM][COLUMN_NUM] = {
    {'1', '2', '3', 'A'},
    {'4', '5', '6', 'B'},
    {'7', '8', '9', 'C'},
    {'*', '0', '#', 'D'}
};
byte pin_rows[ROW_NUM] = {52, 50, 48, 46};      // Les numéros de pin des lignes
byte pin_column[COLUMN_NUM] = {51, 47, 49, 53}; // Les numéros de pin des colonnes
Keypad keypad = Keypad(makeKeymap(keys), pin_rows, pin_column, ROW_NUM, COLUMN_NUM);


LiquidCrystal_I2C lcd(0x27, 16, 2); // Ecran LCD branché à l'adresse 0x27 (trouvable grace au programme fourni) pouvant afficher 16 char par ligne et disposant de 2 lignes


const int captors = 5; // Nombre de capteurs
const Coin coinCaptors[] = {
    {0.1, 2, 9},
    {0.2, 3, 10},
    {0.5, 5, 12},
    {1.0, 4, 11},
    {2.0, 6, 13}
};
Servo servo[captors];


const int stepsPerRevolution = 2038;
const int rpm = 16;

const int itemNumber = 4; // Nombre d'articles différents en vente
Item items[] = {
    {"B17", "Bonbons", 2.5, AccelStepper(AccelStepper::FULL4WIRE, 22, 26, 24, 28, false)},
    {"A12", "Colle", 2.3, AccelStepper(AccelStepper::FULL4WIRE, 32, 36, 30, 34, false)},
    {"C28", "Tictac", 2.1, AccelStepper(AccelStepper::FULL4WIRE, 25, 29, 23, 27, false)},
    {"A22", "Gauffre", 2.8, AccelStepper(AccelStepper::FULL4WIRE, 31, 35, 33, 37, false)}
};

void setup()
{
  Serial.begin(9600);

  // Initialisation de l'écran
  lcd.init();
  lcd.backlight();

  for (int i = 0; i < itemNumber; i++){
    items[i].stepper.setMaxSpeed(300.0);
    items[i].stepper.setAcceleration(100.0);
  }

  // Initialisation des capteurs infrarouges et des servo-moteurs
  for (int i = 0; i < captors; i++)
  {
    pinMode(coinCaptors[i].captorPin, INPUT);
    servo[i].attach(coinCaptors[i].servoPin);
    servo[i].write(150);
  }

  Serial.println("Le programme a démarré");
}

void writeToScreen(int line, String text)
{
  // Clears the screen line
  for (int i = 0; i < 16; i++)
  {
    lcd.setCursor(i, line);
    lcd.print(" ");
  }

  // Writes the text
  lcd.setCursor(0, line);
  lcd.print(text);
}



void giveCoin(int i){
  servo[i].write(40);
  delay(375);
  servo[i].write(150);
  delay(750);
}

void getAllCoins(){
  for (int i = 0; i < captors; i++)
    for (int j = 0; j < 10; j++) giveCoin(i);
}

String waitForCode()
{
  writeToScreen(0, "Distribuino");
  writeToScreen(1, "Code produit ?");

  String productCode = "";
  while (productCode.length() < codeLength)
  {
    char key = keypad.getKey();
    if (key)
    {
      Serial.print("Saisie reçu: ");
      Serial.print(key);

      if (key == '*' || (key == '#' & productCode.length() <= 1))
      {
        Serial.println(", réinitialisation");
        return waitForCode(); // Cancel
      }
      else if (key == '#')
      {
        Serial.print(", suppression du dernier charactère (" + String(productCode.charAt(productCode.length() - 1)) + ")");
        productCode = productCode.substring(0, productCode.length() - 1);
      }
      else productCode += key;

      Serial.println(", saisie totale: " + String(productCode));
      writeToScreen(0, "Code produit ?");
      writeToScreen(1, productCode);
    }
  }
  return productCode;
}

Item* checkCode(String productCode) {
  if(productCode == "DDD") { getAllCoins(); return NULL;}
  
  Serial.print("Le code saisie (" + String(productCode));
  for (int i = 0; i <= itemNumber; i++)
  {
    if (i == itemNumber)
    {
      writeToScreen(1, "Code invalide");
      Serial.println(") est invalide");
      delay(3000);
      productCode = "";
      return NULL;
    }
    else if (items[i].itemCode == productCode)
    {
      Serial.println(") est valide (" + String(items[i].itemName) + ")");
      writeToScreen(0, items[i].itemName);
      writeToScreen(1, "Inserer " + String(items[i].itemPrice) + "e");
      return &items[i];
    }
  }
}

float waitForCoins(Item* item) {
  int last_state[captors];
  float sum = 0;

  while (sum < item->itemPrice)
  {
    char key = keypad.getKey();
    if (key == '*' | key == '#')
    {
      Serial.println("---- Annulation de la transaction ----");
      return sum == 0 ? -9999 : -sum; // Cancel
    }

    for (int i = 0; i < captors; i++)
    {
      int state = digitalRead(coinCaptors[i].captorPin);

      // On teste si le capteur infrarouge détecte un passage
      if (last_state[i] == HIGH && state == LOW)
      {
        Serial.println("pièce de " + String(coinCaptors[i].coinValue) + " détectée");
        sum += coinCaptors[i].coinValue;

        float remaining = item->itemPrice - sum;
        if(remaining > 0) writeToScreen(1, "Inserer " + String(remaining) + "e");
      }

      last_state[i] = state;
    }
  }

  float surplus = sum - item->itemPrice;
  Serial.println("Total " + String(sum) + "€ / " + String(item->itemPrice) + "€ demandés, exédant " + String(surplus) + "€");
  return surplus;
}

void giveMoneyBack(float amount)
{
  for (int i = captors - 1; i >= 0; i--)
  {
    float coinValue = coinCaptors[i].coinValue;
    int quantity = round(amount * 10) / int(coinValue * 10);
    float remaining = amount - coinValue * quantity;
    Serial.println("Reste à rembourser " + String(amount) + "€, rendu de " + String(quantity) + " pièces de " + String(coinValue) + "€, restant " + String(remaining) + "€");

    for (int j = 0; j < quantity; j++) giveCoin(i);

    amount = remaining;
  }
}

void loop()
{
  Serial.println("---- En attente de saisie ----");
  String productCode = waitForCode();
  Item* item = checkCode(productCode);
  if (item == NULL) return;

  Serial.println("En attente de paiement (" + String(item->itemPrice) + "€)");
  float surplus = waitForCoins(item);

  if (surplus >= 0)
  {
    Serial.println("Distribution de " + String(item->itemName));
    writeToScreen(1, "Distribution...");
    item->stepper.enableOutputs();
    item->stepper.move(stepsPerRevolution);
    item->stepper.runToPosition();
    item->stepper.disableOutputs();
  }
  else if(surplus == -9999) return; // Cancelled the transaction before paying anything
  else surplus *= -1; // Started to pay before cancelling

  writeToScreen(1, "Rendu monnaie");
  giveMoneyBack(surplus);

  writeToScreen(0, "Distribuino");
  writeToScreen(1, "Merci a bientot");
  Serial.println("---- Fin de la transaction ----");
  delay(3000);
}

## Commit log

2022-12-14 Déplacement du rapport de séance de Teo
2022-12-14 Lien pour les rapports de séance dans le README
2023-01-04 Scripts des tests avec l'écran
2023-01-04 Rapport de séance 2
2023-01-05 Ajout des medias dans le compte rendu
2023-01-11 Seance 3: Rapport de séance
2023-01-11 Seance 3: Ajout de medias au rapport
2023-01-12 Videos de Teo
2023-01-19 Séance 4: Rapport de séance
2023-01-19 Seance 4: Rapport de séance
2023-02-01 Seance 5: détection des pièces
2023-02-01 Seance 5: Contenu de séance
2023-02-09 Seance 6: Rapport de séance
2023-02-16 Séance 7: Rapport de séance
2023-02-24 Test pour les servo moteurs
2023-02-24 Rendu de monnaie + Ajout de messages
2023-02-28 maj de ce que j'ai fait
2023-03-01 ajout de ce qui a été fait
2023-03-02 Amélioration des tests des servo-moteurs et des capteurs IR
2023-03-02 Test simultané des capteurs IR et des servo
2023-03-02 Detection de l'adresse de l'écran
2023-03-02 Plusieurs stepper, changement des pins et réduction du nombre de cables de l'écran
2023-03-02 Seance 7: Ajout de 2 photos oubliées
2023-03-02 Seance 8: Ajout de vidéos
2023-03-03 Amélioration de l'algo de détection des pièces
2023-03-03 Correction d'un problème de précision
    [coins.ino, distribuino.ino]
2023-03-03 Correction de la mise en forme
    [distribuino.ino]
2023-03-03 Amélioration de l'affichage
2023-03-03 Correction d'un bug permettant de récupérer un article sans payer
    Pour celà, il fallait entrer un code produit valide, puis immédiatement annuler la transaction, le solde était positif (puisque 0 n'as pas de signe), la transaction était considéré comme réussi (l'utilisateur aurait mis le compte exacte)
    [distribuino.ino]
2023-03-07 Ajouts de delay à quelques fct de test
2023-03-08 Désactivation du maintiens des moteurs pas à pas
    Cela permet de réduire l'ampérage nécessaire au système.
2023-03-10 Schéma électrique
    [schema_electrique.fzz]
2023-03-10 MAJ du schema elec
    [schema_electrique.fzz]
2023-03-15 Rapport de projet
2023-03-15 Modélisations 3D de Téo
    [Systeme de trie des pièces partie haute.stl, Système de trie des pièces partie basse.stl, Système de trie des pièces.stl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]
2023-03-15 Ajout de modélisations manquantes
    [10c.stl, 1€.stl, 20c.stl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]
2023-03-15 Ajout d'une photo sur la page de garde
2023-03-15 Ajout d'une vidéo de présentation
